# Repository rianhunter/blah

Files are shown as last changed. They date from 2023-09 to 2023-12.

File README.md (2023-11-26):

# [CXADC][cxadc] clock generator and audio ADC

A project to synchronously clock two (or more) [CXADC][cxadc] PCIe cards and an extra audio ADC from an external clock generator, for [VHS-Decode][vhs-decode] setups.
This enables sync capturing of the two RF streams (RF Video and RF HiFi audio from a VHS), in addition to a stereo audio stream (linear VHS audio).

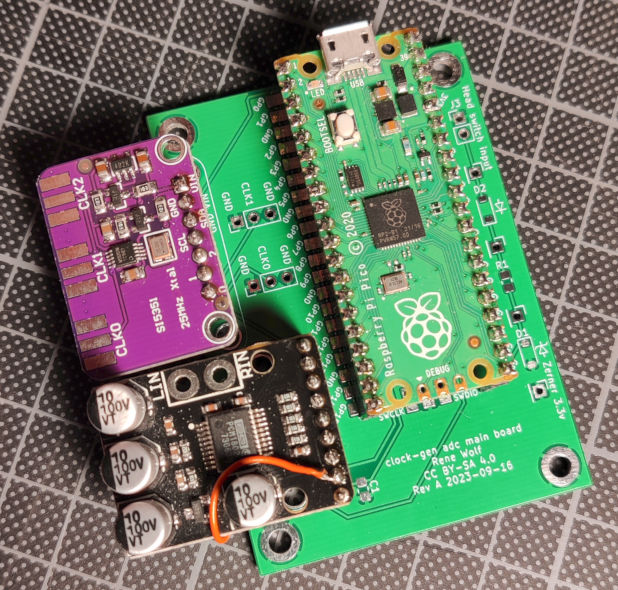
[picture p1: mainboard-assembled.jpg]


The above picture shows the mainboard, which you would typically mount inside your capture PC, along side the 2 CXADC cards.
The below diagram shows how a typical VHS capture is setup using the clock generator + audio ADC (this project).

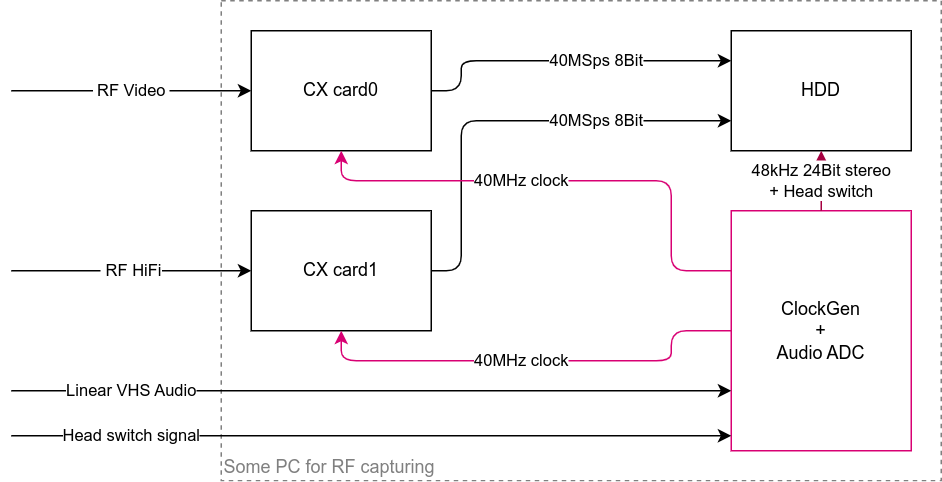
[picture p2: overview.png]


The project consists of 3 main components:
- A PCB adapter that is installed per PCIe card.
  It contains only a couple of passive components per [cx25800-11z data sheet][google-cx25800-datasheet].
- The main PCB that combines a [Raspberry Pi Pico][pi-pico], with an [Adafruit Si5351A Clock Generator Breakout Board][si5351-adafruit], and a [PCM1802 board][pcm1802-product].
- The firmware for the [Raspberry Pi Pico][pi-pico], that implements a USB sound card and also controls the [Si5351A][si5351-adafruit] clock generator.
  The firmware is available pre-build and can be flashed to the [Raspberry Pi Pico][pi-pico] without additional tools.

## Why you would need this

To capture VHS conveniently and then decode it with the amazing [VHS-Decode][vhs-decode], you need two [CXADC][cxadc] PCIe cards and an additional audio ADC.
One [CXADC][cxadc] card will capture the RF video stream at usually 20MSPS 10bit.
The other [CXADC][cxadc] card will capture RF HiFi audio at usually 10MSPS 8bit.
The additional audio ADC captures the linear audio track from the VHS.
So you have 3 independent pieces of hardware that each captures a part of the VHS tapes content.

Each of the 3 pieces has its own quartz oscillator, to drive its logic.
[CXADC][cxadc] PCIe cards usually come with a 28.6MHz quartz, that is commonly replaced with a 40MHz one for better performance.
The additional linear audio stream could be captured with an additional USB audio interface, which of course has its own quartz.

As every real device, quartzes have tolerances, resulting in frequency errors.
E.g. a 40MHz quartz might actually be 40.000005MHz or 39.999995MHz.
This error is due to manufacturing tolerance and basically random.
So each of the 3 quartzes will be slightly different, and you can't really know by how much.
If you just capture from one of these sources, then this tiny error does not matter.
But if you capture 3 streams that all come from the same source, a VHS tape, then it does!

So lets say that one [CXADC][cxadc] card is slightly faster than the other, because its quartz runs a bit faster than the others.
When you've finished your capture from both cards, one file will contain slightly more samples than came from the other stream.
This means the signal / information in both files is actually not aligned with each other any more, like it used to be on the VHS tape.
To align them again, you have to do (manual) post processing to find out how much they differ, and then *resample* one of them to fit the other.
The same goes for the linear audio as well, there may now be slightly more or less samples in your recorded wav file than expected.

This project solves all of this by replacing the quartz crystals on [CXADC][cxadc] PCIe cards with the output from a clock generator.
The clock generator produces the clocks for both cards from a single source (also a quartz).
This single source of course has a slight error, but as both [CXADC][cxadc] cards are now fed from the *same* source, both are now always in sync!
To also cover the linear audio capturing / recording, the project includes a [PCM1802 ADC][pcm1802-product].
This extra audio ADC is also synchronously clocked from the same clock generator, so it is also always in sync to the two [CXADC][cxadc] cards.

As an added bonus, the clock generator is programmable, so the output sample rates for the [CXADC][cxadc] cards can be changed!
This can be configured during system runtime, via the same USB audio interface that also streams the [PCM1802 ADC][pcm1802-product] samples.
And as one more feature, it also contains an additional digital input, that can be connected to the head switch signal of your VHS player.
This signal will be recorded along side the linear audio, enabling even more automation to sync up all those streams.

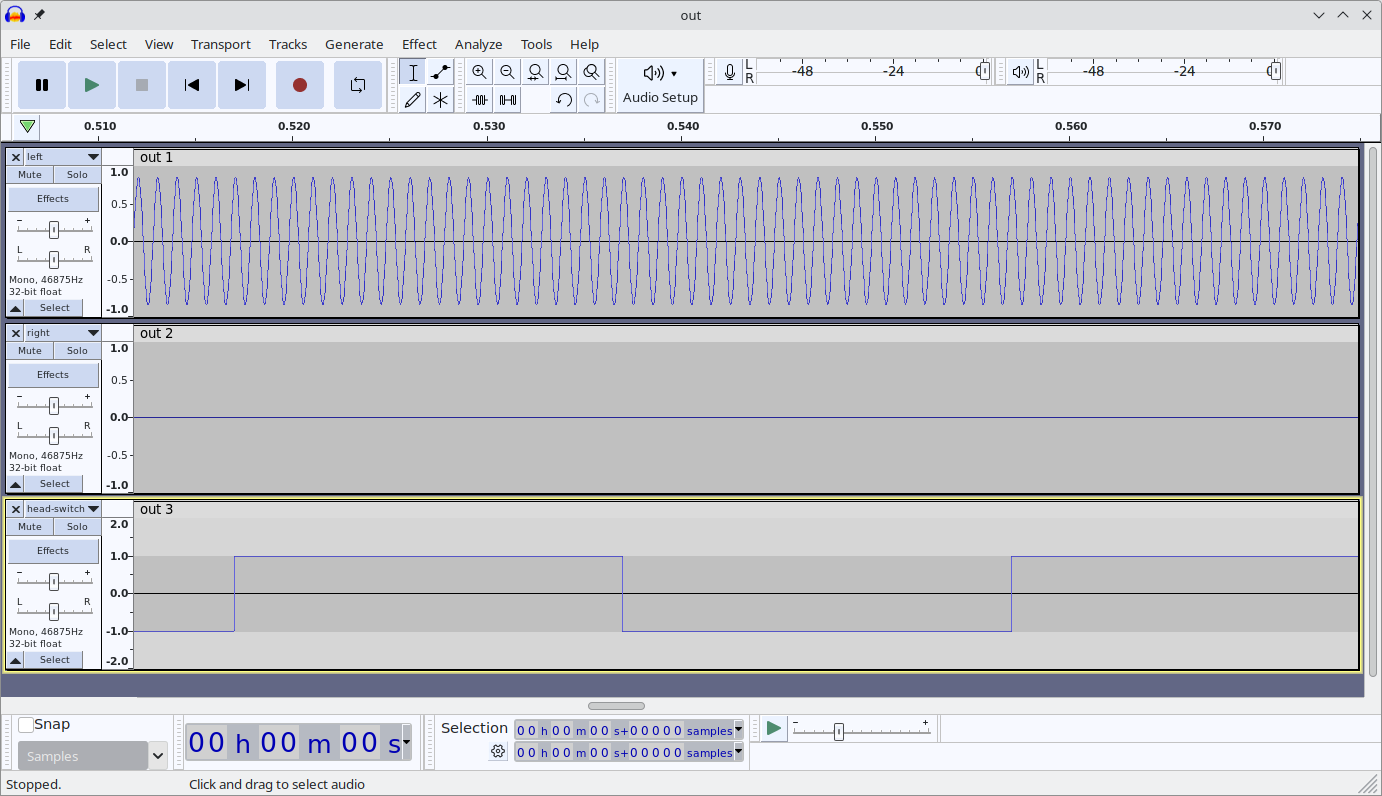
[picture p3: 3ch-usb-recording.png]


The above shows a 3ch recording as captured from the clock generator, a sine wave on the left, silence on the right, and a head-switch signal on the 3rd channel.
Read on to get all the details and find out how to build one yourself.

## Building one yourself

The build and installation guide can be found [over here][build-guide].
Have a look in the [mechanical section too](mechanical) for some (optional) 3D printable parts.
And once you built it, check out the [scripts][scripts] folder which holds some useful tools an examples around using this project.

## System overview and architecture

So you want to contribute, or just understand how it all works, then read on!
Lets start with a logical block diagram of the system.

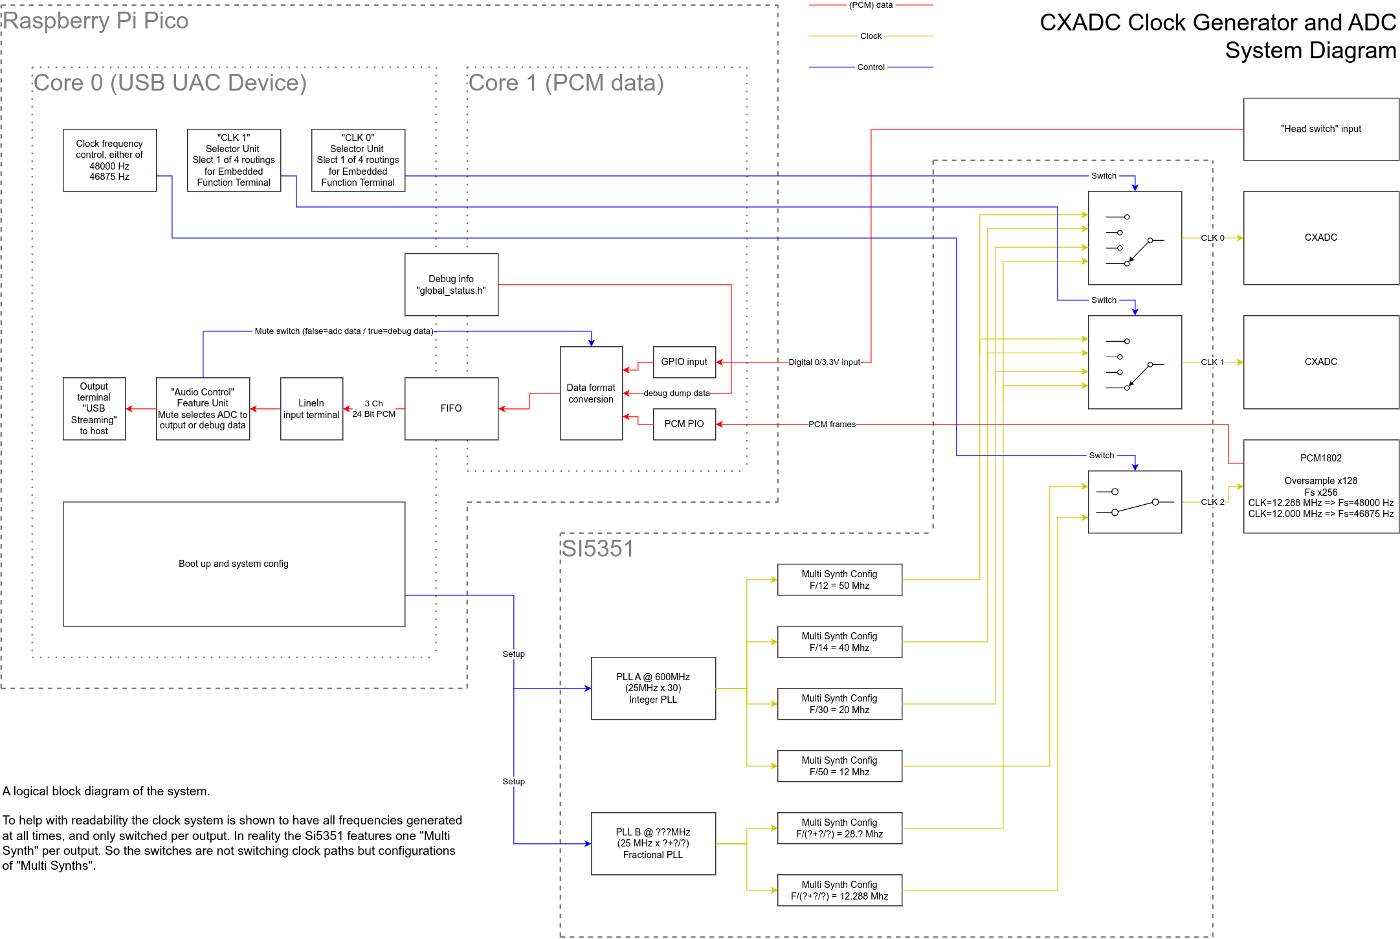
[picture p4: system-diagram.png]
system diagram


The brain of the system is a [Raspberry Pi Pico][pi-pico] that implements a [USB UAC][wiki-usb-uac] device (aka a usb sound card).
The [USB UAC][wiki-usb-uac] device can be used to stream the captured samples from the [PCM1802][pcm1802-product] as a regular sound source.
In addition to audio streaming it also offers control over the sample rates for the ADC and [CXADC][cxadc] cards.
[USB UAC][wiki-usb-uac] is supported by all major OS and should work without the need for any additional drivers.
Here's the output from `arecord` when the clock gen is plugged in:

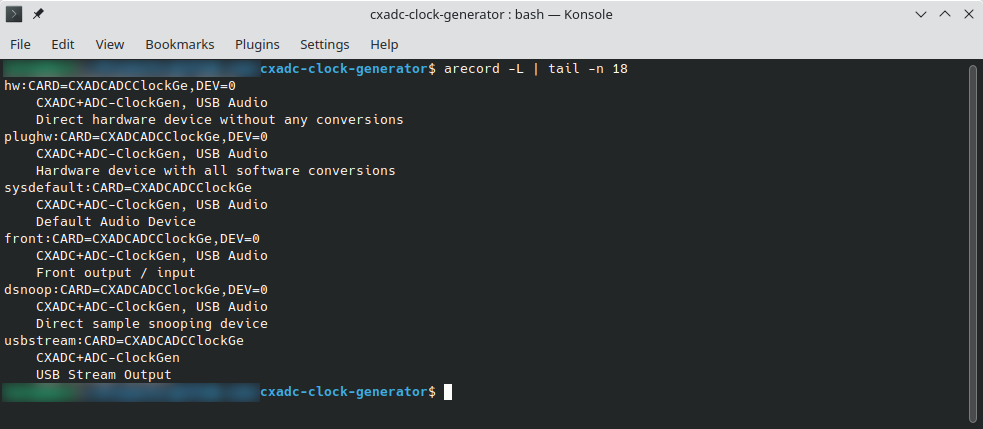
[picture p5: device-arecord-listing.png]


NOTE the following talks a lot about the implementation as a [USB UAC 2.0 audio device][wiki-usb-uac].
The backgrounds and details can be found in the "Device Class Specification Adopters Agreement", aka. [the USB audio specification][usb-auc-20-spec].
So you may want to read through the first 3 chapters to get the full background.

The [USB UAC device][wiki-usb-uac] offers two sample rates for the [PCM1802][pcm1802-product], that can be switched via a UAC clock source.
This is [done automatically by your OS / sound system][multi-samplerate] so just select your desired capture rate with your sound recorder of choice.
To enable clock frequency switching on the [CXADC][cxadc] cards however a UAC clock source would most likely not work.
ALSA and other sound systems will configure UAC clock sources only when capturing from a linked stream.
The [CXADC][cxadc] cards however are not linked to any audio data you could stream from the UAC device.
So instead the various clock rates are implemented as (fake) internal audio streams that can be switched with a UAC switch control.
Internal audio streams are per UAC specification not available to the outside and as such should not trouble OS sound systems for not offering a way to stream their data.
Every clock frequency is represented as one (virtual/internal/fake) input stream, and each of the two [Si5351A][si5351-adafruit] clock output is represented as one (virtual/internal/fake) output.
So to the OS / sound system this looks like a switch matrix of various audio stream sources, switched onto two outputs.
This will generate entries in the usual mixer widgets / apps, that let you control your general sound card settings.
But instead of switching actual audio streams, the UAC selector unit of course switches clock frequencies for the attached [CXADC][cxadc] cards.

This is all a bit abstract, so here's how those switches are displayed in `alsamixer` (you can switch the rates simply using the arrow keys on your keyboard):

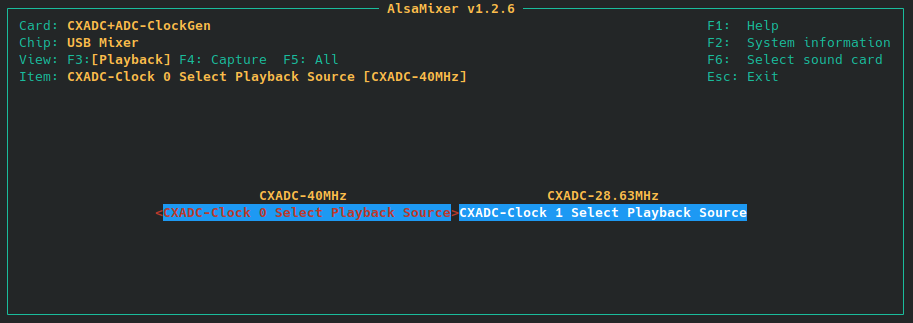
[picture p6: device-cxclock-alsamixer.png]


And here's how `amixer` can be used to script switching the clock rate on output 0:



To help with readability and to more closely match the USB UAC implementation, the above system diagram shows the clock system to have all frequencies generated at all times, and then switched per output.
In reality the [Si5351A][si5351-adafruit] features only one "Multi Synth" per clock output. 
So the switches are not switching clock paths but rather configurations of "Multi Synths".

The setup offers a couple of options for both the [PCM1802][pcm1802-product] audio ADC and the [CXADC][cxadc], but not all of them are of equal quality.
Inside the [Si5351A][si5351-adafruit] clock generator, two [PLLs][pll-wiki] are used to generate intermediate frequencies.
Those intermediate clock are then further divided to get the desired clock frequencies at the 3 outputs.

PLL A is running in integer mode, which means only whole number multipliers are used, resulting in no added [jitter][jitter-wiki].
Further more the subsequent "multi synth" dividers are also in integer mode, again resulting in no added [jitter][jitter-wiki].
But this limits the clock outputs options to only frequencies that can be produced by one multiplication and one division with only whole numbers.
Based on the 25 MHz source that is included on the [Si5351A][si5351-adafruit] board, this enables CXADC *sampling clocks of 20 MHz, 40 MHz and 50 MHz*.
The [PCM1802][pcm1802-product] needs a clock of 256 times the frequency of the desired output audio sampling rate.
The PLL A path generates a 12 MHz output which results in an exact (without rounding error) *46875 Hz / 46.875 kHz* sample rate for the audio stream.
This uncommon rate does not degrade the performance of the [PCM1802][pcm1802-product] ADC and offers analog bandwidth that is above CD quality.
Using common tools (sox or ffmpeg) the captured pcm data can be fully automatically resampled to the more common 48 kHz or 44.1 kHz in an offline processing step.

PLL B is running is running in fractional mode, yielding an increased clock [jitter][jitter-wiki].
Together with fractional configuration in the subsequent "multi synth" dividers, two more clock rates are possible.
The [CXADC][cxadc] can be clocked with the same frequency as the stock crystal 28.636360 MHz.
And the [PCM1802][pcm1802-product] can be clocked with a 12.288 MHz, giving the more common 48 kHz as output sample rate.
In ADCs [the higher the clock jitter the worse the sampling quality][jitter-paper] will be.
So you should avoid these sampling rates if you can and only use the ones from the integer mode PLL A.

## Debugging, global status and the mysterious mute switch

As this project is put together from various components (main board, sub boards, etc.), quite a few things can go wrong.
The firmware will output debugging information over the UART0 on the Pi Pico (GPIO0 / Pin1).
So hooking up a serial adapter is a good idea when working on the code (see also [dbg.h](firmware/src/dbg.h)).
However when just assembling the project, users may not have the option to do that, so a more practical way of obtaining debugging info is needed.
This does not have to be all the debug output that happens everywhere, but it should be enough to find common problems.

[USB UAC][wiki-usb-uac] unfortunately does not give many options to achieve that.
There is a "Memory Requests" (chapter [5.2.7.1][usb-auc-20-spec]) which would be perfect, but there is no common user space tool available.
User space support with regular tools is important as this is what users will have, and what the [collect-info.sh][scripts] script can use.
So instead of writing a custom tool, we just re-use the audio data that streams from the ADC.
But that can't be happening all the time, and the ADCs might even be non-working, so there must be a way to switch this on and off.
This can be done with a simple mute switch on a feature unit.
If muted debug info will be output, if un-muted (the default after boot), then actual ADC data will be streamed.

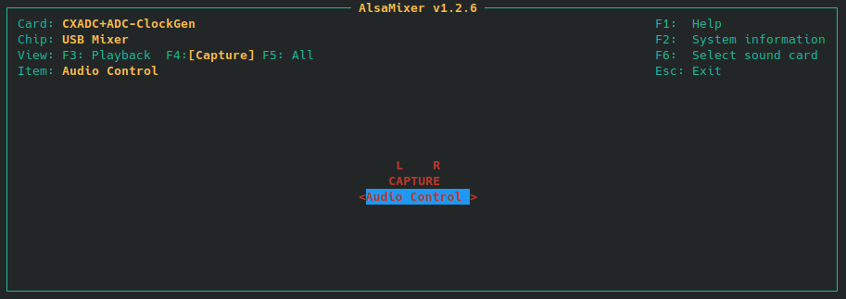
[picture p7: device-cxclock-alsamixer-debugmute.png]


The above shows how `alsamixer` displays the on / un-muted state (can be toggled with the *space* bar).

Now what is inside the debug info, you may ask?
Well there is a global status object [global_status.h](firmware/src/global_status.h) that is updated at the relevant places in the code.
It contains flags that indicate errors, and some other values of interest.
This object is dumped in the audio data and streamed to the host.
In other words, to get the debug data, just mute the stream and record a short piece of "audio" with `arecord`.

Have a look at the troubleshooting section of the [build guide][build-guide] if you need help getting the system running.

## Versioning

The firmware / software part is using [Semantic Versioning][semver], referring to the USB device interface.
Tags on this repository will carry the firmware / software version.

The PCBs are versioned with a letter revision.
These revisions do not imply any compatibility, and are solely used to differentiate one revision from another.
PCB revision overview:
- VT610ex clock generator adapter
  - Revision A - never released
  - Revision B - first public release
  - Revision C - some updates to the silkscreen and moved one via to get PcbWay support, otherwise identical to Revision C
  - Revision D - update connector footprint to better fit SMA edge connector and still be compatibile with pin header edge mount
- Clock generator main board
  - Revision A - first public release
  - Revision B - fixes the IO VDD for Si5351, which should be 3.3V, Rev A erroneously had it at VSys
  - Revision C - fixes the 3.3V from PCM1802 being driven by Pi Pico, instead this is an output and should be left open

## Changelog

See [CHANGELOG.md](CHANGELOG.md).

## Releases

See [releases](https://gitlab.com/wolfre/cxadc-clock-generator-audio-adc/-/releases) for PCB gerbers and firmware images ready to flash.

# License

The content of this repository is under various licenses.
The PCB parts are generally under *Creative Commons Attribution-ShareAlike 4.0*, but contains external sources (with compatible licenses).
The source code is mostly under 3-Clause BSD, but contains external sources with compatible licenses mixed in.
Source files carry an [SPDX][spdx] header to indentify.
For details see the individual *LICENSE\** files in the respective folders they apply to, firmware zip packages contain a copy of all the applicable license files.

[cxadc]: https://github.com/happycube/cxadc-linux3/
[pi-pico]: https://www.raspberrypi.com/products/raspberry-pi-pico/
[si5351-adafruit]: https://www.adafruit.com/product/2045
[pcm1802-product]: https://www.ti.com/product/PCM1802
[google-cx25800-datasheet]: https://www.google.com/search?q=DSH-201233A
[semver]: https://semver.org/
[wiki-usb-uac]: https://en.wikipedia.org/wiki/USB#Audio_streaming
[multi-samplerate]: https://stackoverflow.com/questions/41702932/usb-audio-class-2-0-how-to-support-multiple-bit-rates-sample-rates
[pll-wiki]: https://en.wikipedia.org/wiki/Phase-locked_loop
[jitter-wiki]: https://en.wikipedia.org/wiki/Jitter
[jitter-paper]: https://www.analog.com/media/en/reference-design-documentation/design-notes/dn1013f.pdf
[spdx]: https://spdx.dev/
[vhs-decode]: https://github.com/oyvindln/vhs-decode
[usb-auc-20-spec]: https://www.usb.org/sites/default/files/Audio2.0_final.zip
[scripts]: scripts
[build-guide]: build-guide/README.md

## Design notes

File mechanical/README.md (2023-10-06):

# Mechanical parts of the project

This folder holds mechanical parts, like enclosures or pc case brackets.

## [enclosure-01](enclosure-01)

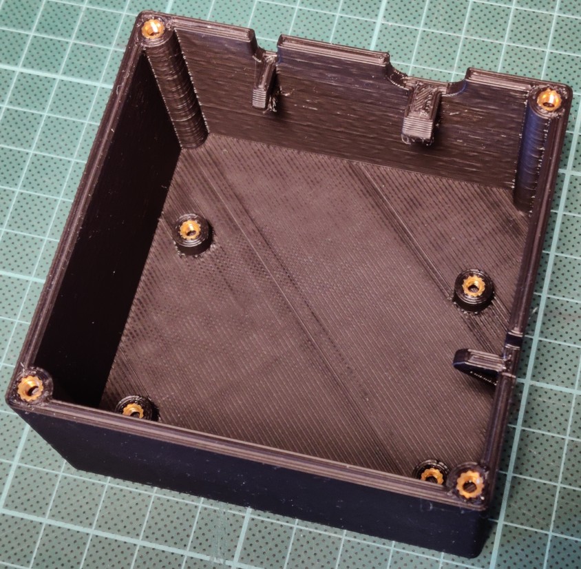
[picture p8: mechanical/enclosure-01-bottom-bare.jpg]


This is a simple box enclosure with enough room for all PCBs.
Can be printed in simple PLA on regular 3D printers.
Designed for M3 threaded insert from [CNC Kitchen](https://cnckitchen.store/products/gewindeeinsatz-threaded-insert-m3-short-100-stk-pcs), but possibly fits others a well.
FreeCAD model is fully parametric so you can change as needed (have a look at the included sheet called "m" to change heat set inserts diameters).

Optionally lined with copper for shielding.

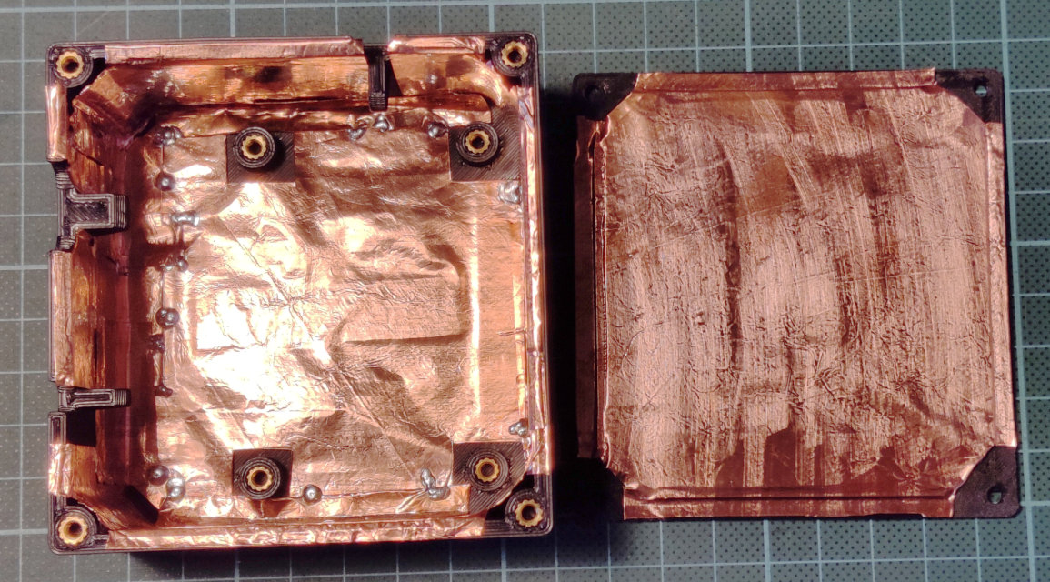
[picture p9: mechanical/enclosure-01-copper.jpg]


Optionally with a mounting base and retaining clip.
The mounting base can be glued into a PC case, and the enclosure box can be seated into it, then fixated with the retaining clip.

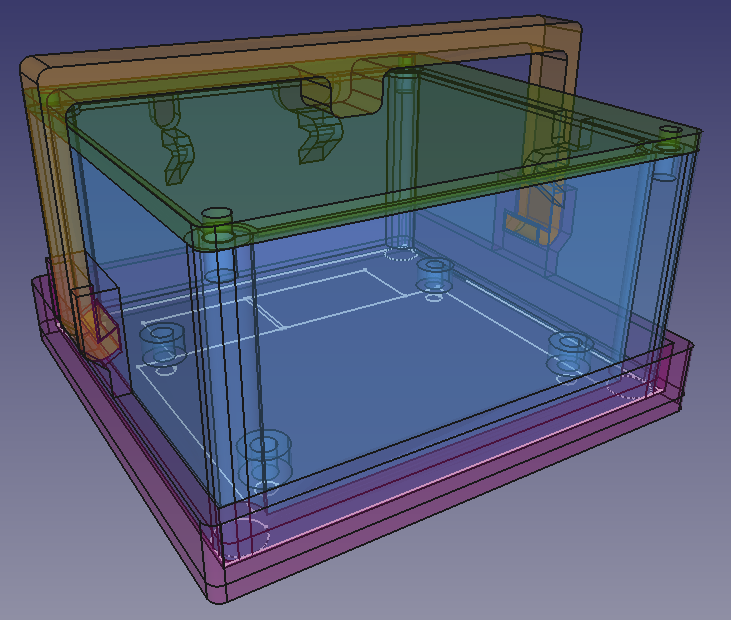
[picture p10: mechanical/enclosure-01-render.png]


## [pc-bracket-rca](pc-bracket-rca)

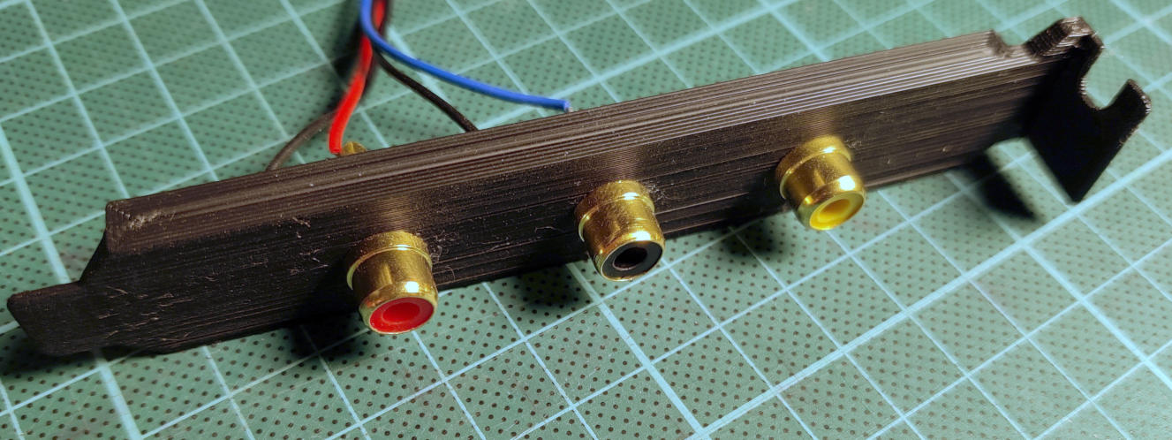
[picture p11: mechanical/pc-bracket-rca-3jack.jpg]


This is a simple PC card bracket with either 2 or 3 RCA jacks.
Can be used for PCM1802 ADC input (L+R) and optionally head switch input on the 3rd jack.
Printable in simple PLA on regular 3D printers.
FreeCAD model is fully parametric so you can change as needed (have a look at the included sheet called "m-rca" to change RCA jack hole diameters).

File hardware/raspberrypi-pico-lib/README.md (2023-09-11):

# KiCad-RP-Pico

A 3D footprint of the Raspberry Pi Pico board for KiCad.
To remove the need for git submodules and thus possibly broken KiCad projects, the symbol lib was copied to this repository.
The original project source can be found [over here][src].
A tweet with an image of your Raspberry Pi Pico project with a link [to the original project][src] and author (@tpcware) would be greatly appreciated.

[src]: https://github.com/ncarandini/KiCad-RP-Pico/tree/main

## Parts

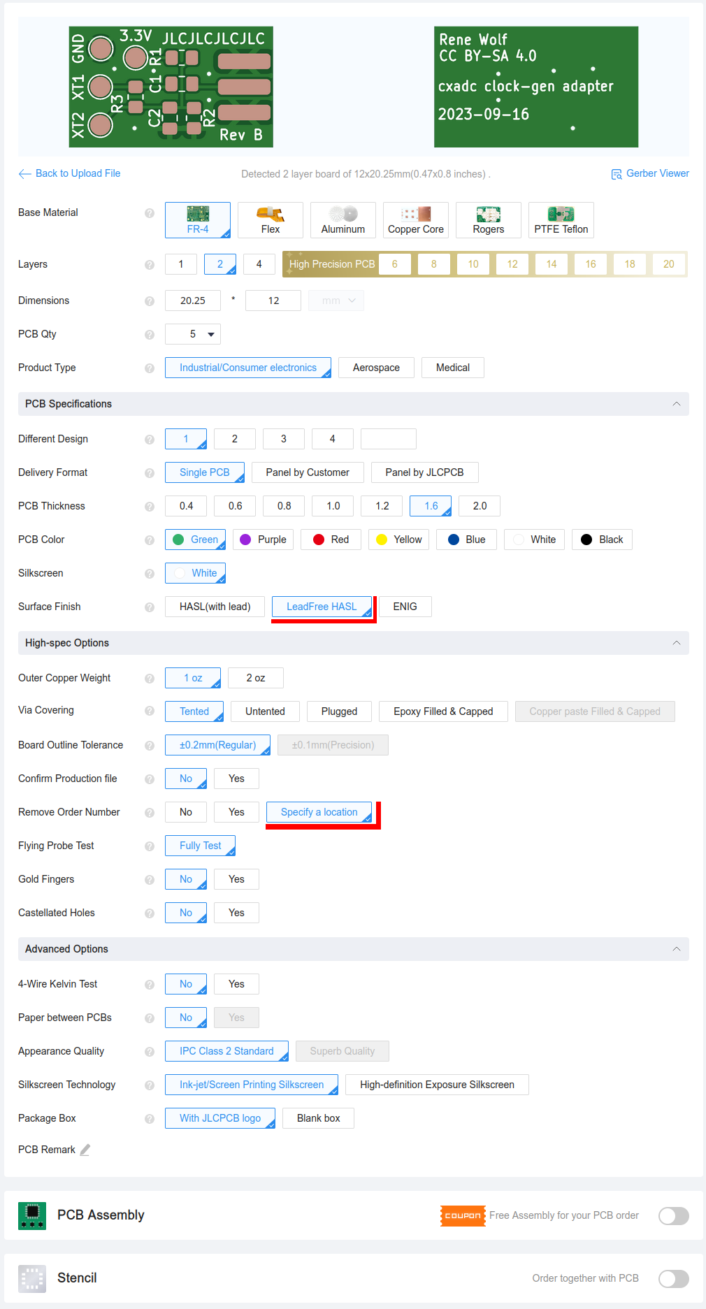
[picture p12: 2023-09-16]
hardware/jlc-2023-09-order-example.png

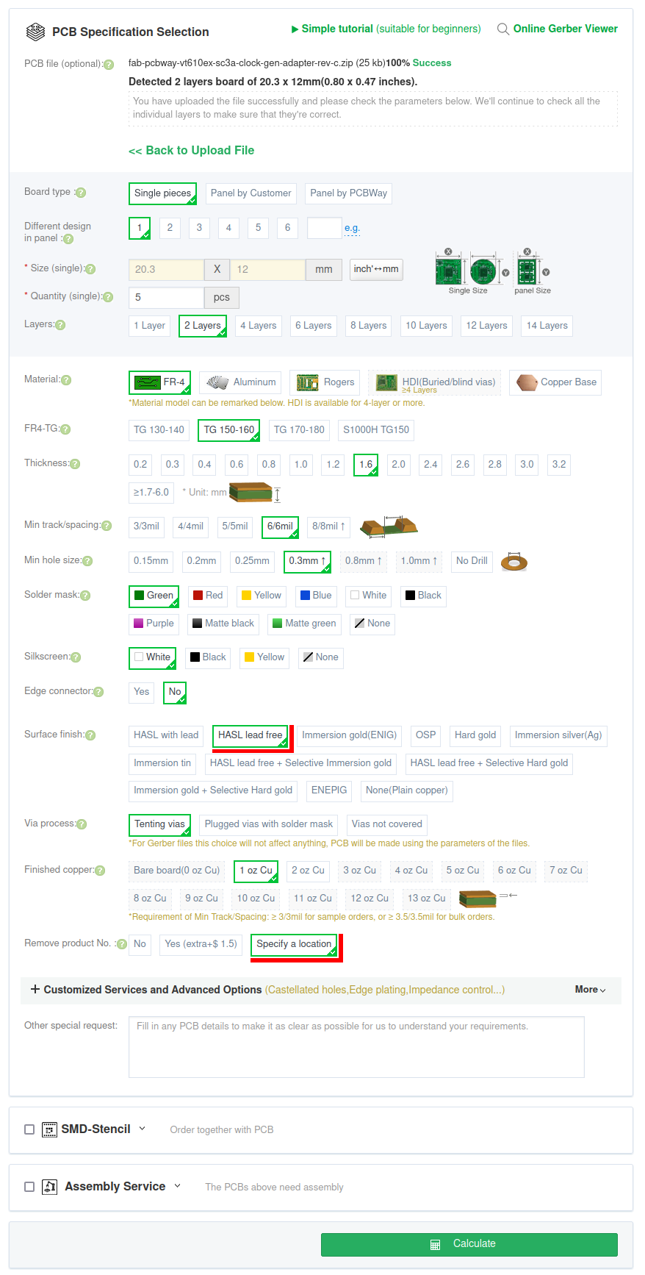
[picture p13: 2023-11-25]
hardware/pcbway-2023-11-order-example.png

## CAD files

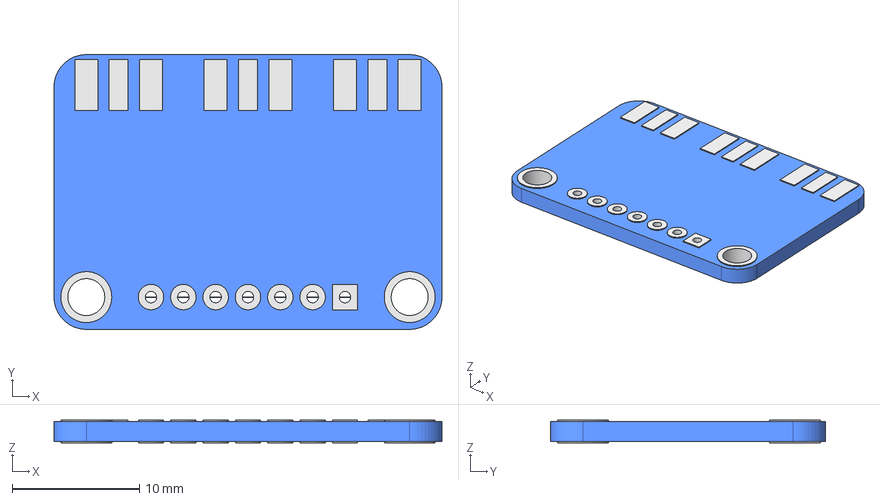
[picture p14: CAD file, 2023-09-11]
hardware/main-board/adafruit-si5351-freecad/adafruit-si5351-breakout.FCStd
30.5 x 21.6 x 1.80 mm
pcb
pads-th
pads-smd

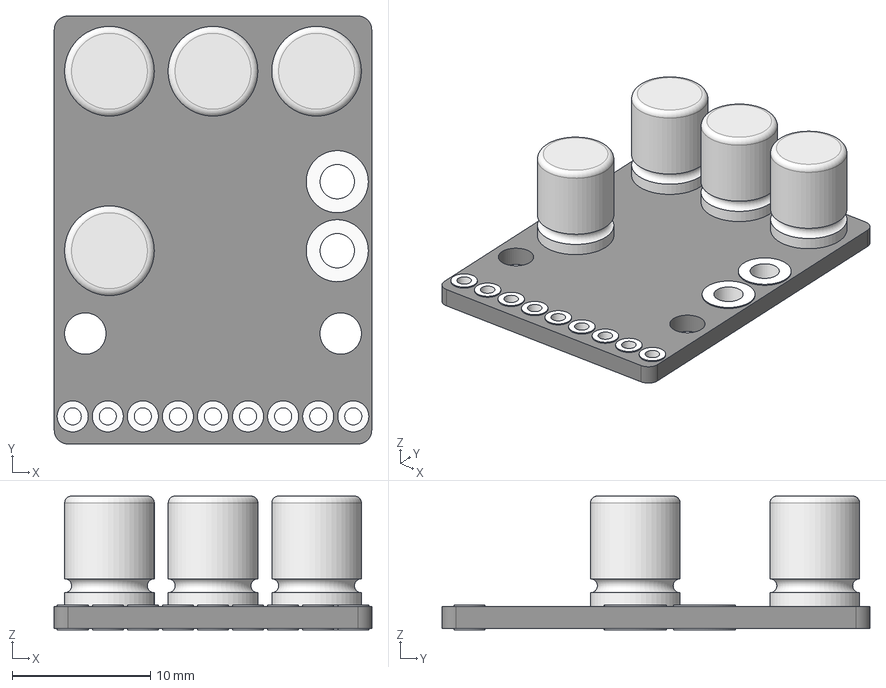
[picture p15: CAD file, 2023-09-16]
hardware/main-board/black-pcm1802-freecad/black-pcm1802-breakout.FCStd
23.0 x 31.0 x 9.70 mm
pcb
hole-plating
cap-back-1
cap-back-2
cap-back-3
cap-middle-1

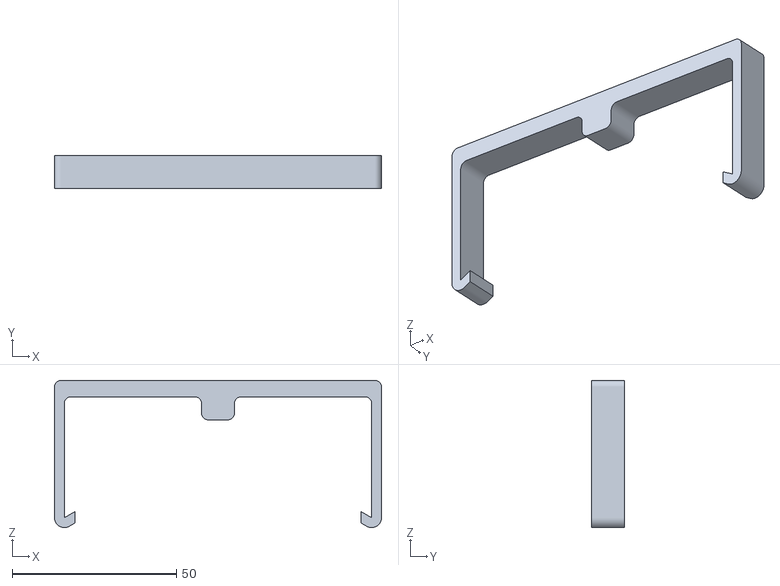
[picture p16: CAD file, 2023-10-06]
mechanical/enclosure-01/mount-clip.stl
99.5 x 10.0 x 44.8

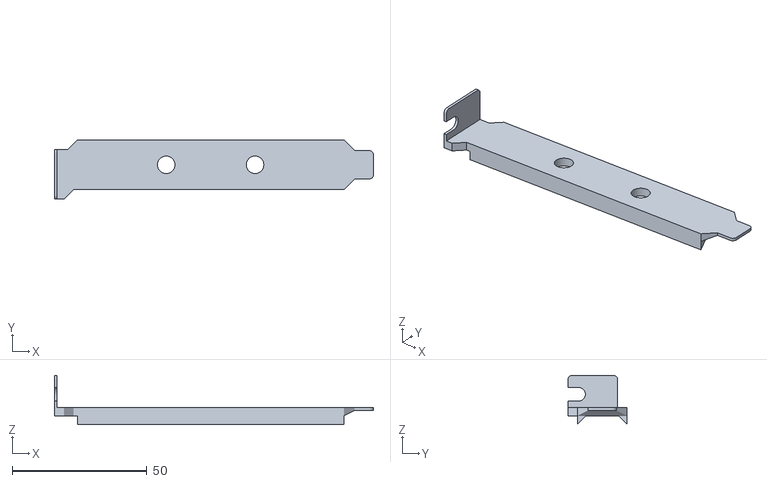
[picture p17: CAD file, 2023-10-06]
mechanical/pc-bracket-rca/bracket-2rca.stl
118.5 x 22.0 x 18.2

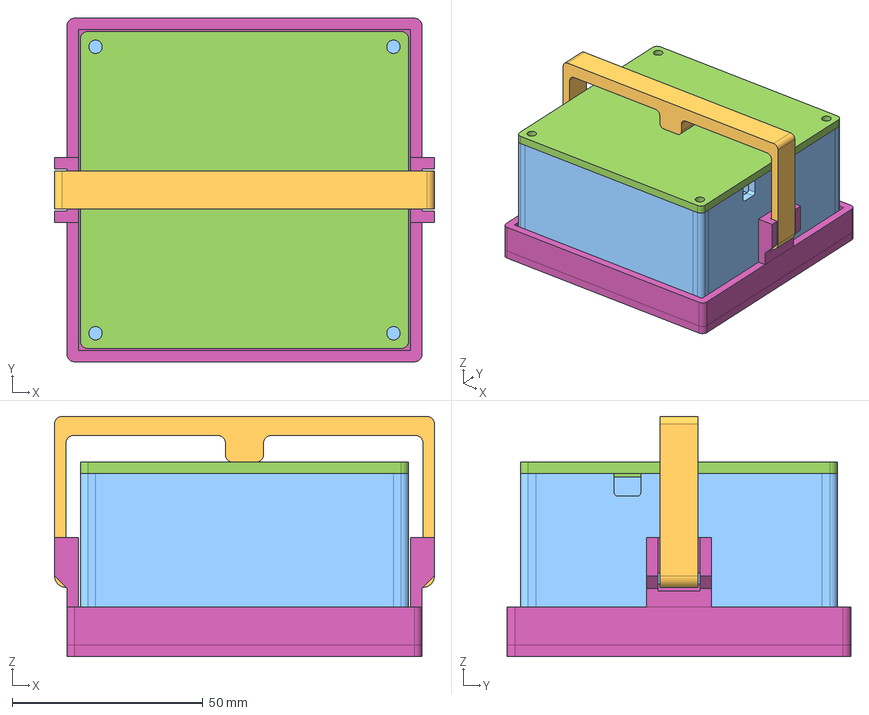
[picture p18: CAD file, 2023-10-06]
mechanical/enclosure-01/enclosure-01.FCStd
99.5 x 90.0 x 62.9 mm
box-bottom
box-lid
mount-clip
mount-base

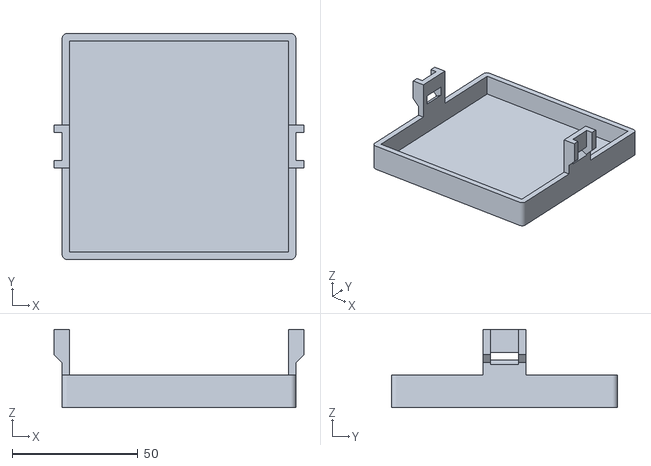
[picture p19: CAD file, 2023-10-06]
mechanical/enclosure-01/mount-base.stl
99.5 x 90.0 x 31.1

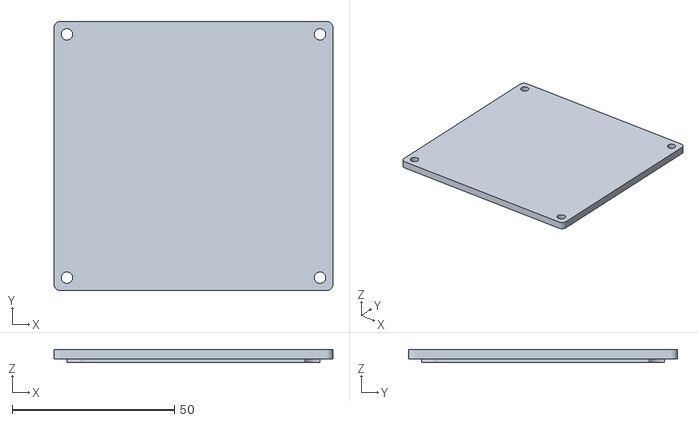
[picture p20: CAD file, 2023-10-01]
mechanical/enclosure-01/box-lid.stl
86.0 x 83.0 x 4.00

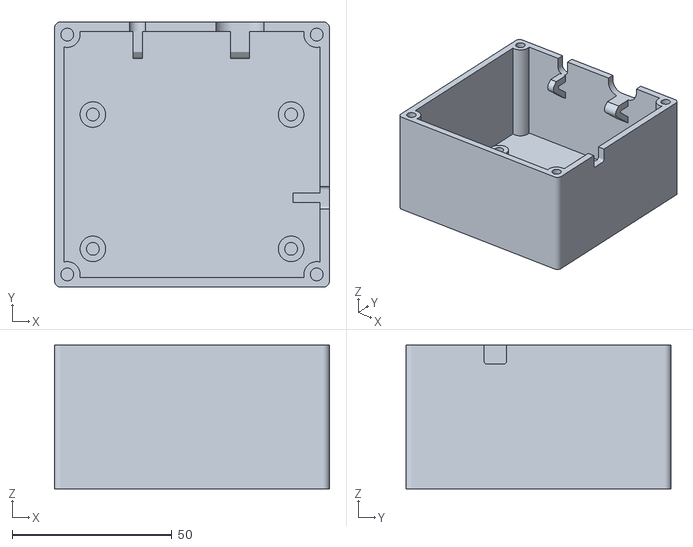
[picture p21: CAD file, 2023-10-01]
mechanical/enclosure-01/box-bottom.stl
86.0 x 83.0 x 45.0

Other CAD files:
mechanical/pc-bracket-rca/bracket-3rca.stl
mechanical/pc-bracket-rca/pc-bracket-rca.FCStd

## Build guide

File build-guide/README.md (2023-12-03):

# Build and installation guide

Ahh so you've come here to build the project, *excellent*!

Before you start ordering and building, you should read the entire guide at least once so you know what to expect.
You will be assembling the project from various ready made components and solder them together.
Most components can be ordered in a finished and populated state, basically you only need to wire them up.
But the two main PCBs of this project need to be ordered with either [JLCPCB][jlcpcb] or [PcbWay][pcbway] and then some SMD parts populated manually.
Don't worry though all SMD parts are rather large 0805, and ordering them with [JLCPCB][jlcpcb] is fast and cheap!
The [hardware](../hardware) section of this project includes the full [KiCad][kicad] project files, so you can also generate gerbers for a different manufacturing house.

If you are new to soldering electronics, learning about it is a bit beyond this guide.
However you may want to start looking here, as these videos cover the things needed for this guide:
- Branchus Creations Beginner's Guide to Soldering Electronics [Part 1](https://www.youtube.com/watch?v=M2Jf8cebwCs) and [Part 2](https://www.youtube.com/watch?v=BPuH1Z2npoQ)
- Electronoobs [SMD Soldering Tutorial | Guide | Tools | Tecniques | Stencil](https://www.youtube.com/watch?v=fYInlAmPnGo)

The steps covered here will assemble the electronic components and flash the firmware on the Raspberry Pi Pico.
Mounting the finished build in your particular PC / setup is beyond the scope of this guide.
You can however have a look in the [mechanical section](../mechanical) for some 3D printable parts that may suit your needs.

This guide will assume you have two PCIe CX based capture cards ready to be modded.
Have a look [over here][vhs-decode-wiki-cxcard] for some sources and options on acquiring those cards.
The instruction in here possibly work with other models, but they were tested and confirmed working with these variants:
- *VT610EX Rev:SC3A VTImage 19.07* capture cards, white pcb, featuring a *CX25800-11Z*

If your board / card variant is not listed here, go over the guide and compare the instructions to your card.
If the parts they are referring to also exist on your board, there's a good chance this guide also works for you.

## General prerequisites

You will be dealing with high frequency digital clock signals.
Even though these are more immune to problems than analog signals, you should have a [Digital storage oscilloscope][wiki-dso] at hand.
You can assemble all of this project without one, but you probably want to check signal integrity, before putting everything together.
In order to correctly assess the signals, your scope should have an analog bandwidth of at least 20MHz, better 100MHz.

You should also have a [Multimeter](https://en.wikipedia.org/wiki/Multimeter#Digital) ready, to test continuity, and verify resistance and possibly capacity.

And finally you will need some basic soldering equipment. 
A fine tip (e.g. 1mm) soldering iron and some good lead-free solder.

Each of the PCBs has a shopping list of components you need to order.
For the SMD parts I always order some spares, in case I make a mistake.
So put add something like 10% additional parts, but at least one extra component per type.

## Ordering PCBs

If you choose a manufacturing house other than [JLCPCB][jlcpcb] or [PcbWay][pcbway], you already know what you need.
The [releases section][releases] of this project holds the finished gerbers for ordering directly from [JLCPCB][jlcpcb] or [PcbWay][pcbway].
When ordering from [JLCPCB][jlcpcb], you should check [these settings (valid as of Sep. 2023)](../hardware/jlc-2023-09-order-example.png) for both boards.
When ordering from [PcbWay][pcbway], you should check [these settings (valid as of Nov. 2023)](../hardware/pcbway-2023-11-order-example.png) for both boards.
The minimum quantity (as of Nov. 2023) is 5 per PCBs (on both manufacturing houses), so for a single clock gen with two [CXADC][cxadc] cards, you will have some spares.

## Building PCB 1 - VT610ex clock generator insert

This PCB adapter will replace the quartz oscillator on a VT610ex PICe capture card.
So you will need to build one these PCBs / adapters per [CXADC][cxadc] card you have.

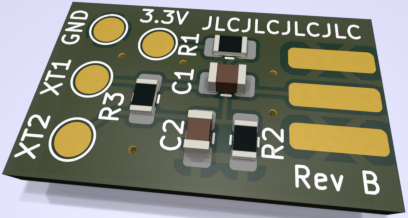
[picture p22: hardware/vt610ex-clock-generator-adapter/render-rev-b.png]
render


**Shopping list** for *one single* adapter (multiply items by number cards you want to modify):
- 1x PCB "clock-gen-adapter" probably from [JLCPCB][jlcpcb]
- 2x 0805 SMD resistor 1K Ohm, 5% tolerance or better
- 1x 0805 SMD resistor 10K Ohm, 5% tolerance or better
- 1x 0805 SMD capacitor 1.5 nF, 6V or greater, ceramic X5R or X7R
- 1x 0805 SMD capacitor 10 nF, 6V or greater, ceramic X5R or X7R
- Thin wire in 4 colors, AWG 30 (0.25mm) to AWG 20 (0.81mm) works well
- The PCB supports two options for connection to the mainboard
  - Either with pin header / socket and a custom made coax cable
    - 1x 3x2.54mm pin header, straight (it will be mounted "lying / sideways" on the PCB)
    - 1x 3x2.54mm pin socket, straight (it will be soldered as a connector to the coax cable)
    - About 50cm of RG174 coax cable.
      This will be used to connect the adapter to the clock gen mainboard, and the exact length depends on your installation situation.
      You can use a different type of cable here, but the RG174 is still flexible enough to be convenient to handle.
    - Some heat-shrink tube to cover the coax and pin socket
    - Double sided tape to attach the adapter PCB to the back of the CX card
  - Or via SMA edge connectors, which should be paired with another one on the Si5351A sub board
    - 2x Female edge mounting SMA connectors (one for the adapter, and one for the mainboard / Si5351A sub board).
      There are a number of manufacturers that produce these, but they should be about 6-7mm side-to-side, and have a 1.6-1.8 mm PCB clearance, e.g [CON-SMA-EDGE-S](https://mou.sr/3t0dMKq)
    - 1x Male to male SMA cable with a length matching your installation requirements, e.g. [250mm 135101-03-M0.25](https://mou.sr/3Tggbf5)
    - Thick double sided tape to attach the adapter PCB to the back of the CX card.
      Thickness must give enough clearance for the edge mounting SMA connectors, about 2mm should be fine.

First populate the SMD components on the PCB like so:
- R1, R2 as 1K Ohm
- R3 10K Ohm
- C1 1.5 nF
- C2 10 nF

Then solder the 3x pin header sideways onto the edge of the PCB, or solder the edge mounting SMA connector.
Finally solder about 10 cm (4 inches) of wire to each of the pads (XT1, XT2, GND, 3.3V).
Use different colors per pad for easier installation.
You should end up with something like this (pin header shown, not SMA edge connector):

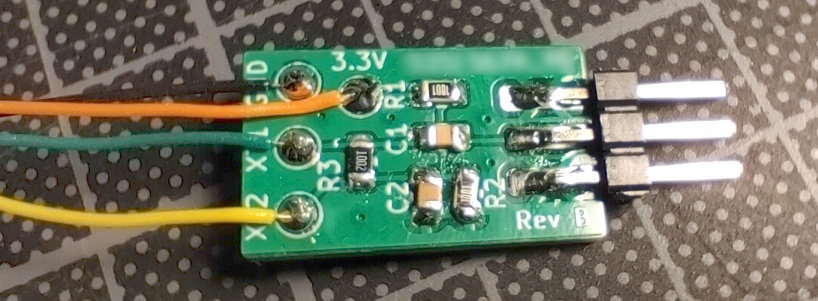
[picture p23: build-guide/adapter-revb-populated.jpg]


If you chose the SMA connector option, this completes the adapter board.

Otherwise you now need to finish the coax cable and connection.
So take the desired length of RG174 coax cable and solder the 3x pin socket to one end.
Remember you can always shorten the cable later, so add some extra length here.
The center pin is the clock signal, the other two pins are shield / ground.
Finally with some heat shrink over it, you should end up with something like this:

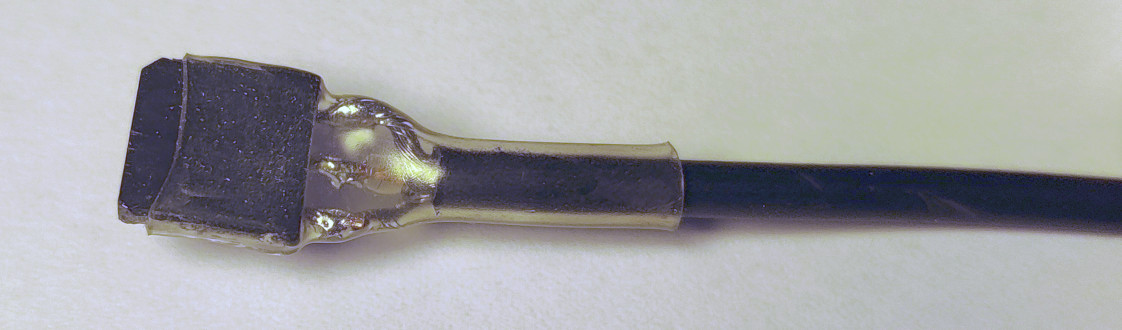
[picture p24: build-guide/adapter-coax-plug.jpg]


This completes the adapter board, so it can be later mounted to a CX card.

## Building PCB 2 - Clock generator and ADC mainboard

This PCB combines a [Raspberry Pi Pico][pi-pico] with a [Adafruit Si5351A Clock Generator Breakout Board][si5351-adafruit], and a [PCM1802 board][pcm1802-product].
The clock generator produces 3 clocks, clock 0 and clock 1 are available for two [CXADC][cxadc] cards, clock 2 drives the [PCM1802 ADC][pcm1802-product].
Optionally a digital input pin can sample the *head switch signal* from your VCR, or any other sync signal you choose.

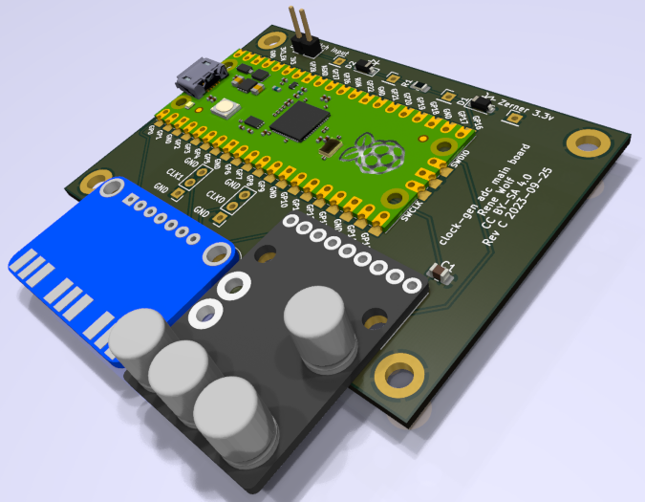
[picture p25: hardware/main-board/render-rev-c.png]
render


The various sub components can be soldered / mounted on the mainboard, with only pin headers as connection.
However adding pin sockets will enable easy component swapping later, and greatly help with troubleshooting!

**Shopping list mandatory components only** for one mainboard:
- 1x PCB "clock-gen mainboard" probably from [JLCPCB][jlcpcb]
- 1x [Raspberry Pi Pico][pi-pico] (wireless variant can be used, but is not needed, and offers no extra features)
- 1x [Adafruit Si5351A Clock Generator Breakout Board][si5351-adafruit], compatible clones may be found at other places as well.
  If you chose to use SMA edge connectors for the clock lines then the mechanical stress will be taken up by the Si5351A sub board instead of the mainboard PCB.
  Depending on your specific installation, you should add some mechanical support here.
- 1x PCM1802 board, unknown manufacturer but can be [found on aliexpress][ali-pcm1802-search].
- 1x Micro USB cable to connect the Raspberry Pi Pico to your target system.
- 2x 20x2.54mm pin header, straight (mounting the Raspberry Pi Pico)
- 1x 9x2.54mm pin header, straight (mounting the PCM1802 board)
- 1x 7x2.54mm pin header, straight (mounting the Si5351A board)
- About 50cm of shielded, stereo audio cable to connect the PCM1802 stereo inputs to some connector.
  I can recommend [SOMMER Cable SC-Cicada SO-D14](https://shop.sommercable.com/en/Cable/Bulk-Cable-Audio/Patch-Mikrofonkabel-SC-Cicada-SO-D14-200-0451.html) or the [Belden 8451](https://www.belden.com/products/cable/audio-cable/analog-audio-cable/8451).
  The exact length depends on your installation situation.
- 2x RCA socket for stereo analog input.
  Feel free to choose a different connection type for your setup.
  This build guide will skip over this part, and it is listed here only to remind you to include this in your shopping spree.

**Shopping list optional components** for one mainboard, in addition to the list above:
- 2x Heat sinks for the CX chips, with adhesive thermal pads to mount.
  As the clock generator will deliver higher clock frequencies than the stock crystal, the chips will get warmer.
- 2x 20x2.54mm pin socket, straight (making the Raspberry Pi Pico removable again)
- 1x 9x2.54mm pin socket, straight (making the PCM1802 board removable again)
- 1x 7x2.54mm pin socket, straight (making the Si5351A board removable again)
- 1x 0805 SMD capacitor 10 µF, 6V or greater, ceramic X5R or X7R.
  This can be used to further decuple the 5V analog rail on the PCM1802 chip.
  It is unlikely you will need this unless your USB 5V supply is quite bad.
  But then you probably should not be using the system to capture analog RF signals either ...

**Shopping list for optional head switch signal input** for one mainboard, in addition to the lists above (can be left entirely unpopulated if you don't need that):
- 1x 0805 SMD resistor 1K Ohm, 5% tolerance or better.
- 1x 3.3V Zener diode either SMD SOD-123 package or through hole
- 1x regular signal diode either SMD SOD-123 package or through hole
- 1x 2x2.54mm pin header, straight (serves as a connection point on the PCB for the signal input).
- 1x 2x2.54mm pin socket, straight (serves as a connector plug).
- About 50cm of shielded, cable for the head switch signal.
  This signal is rather low frequency and digital, so most cables should work.
  You can just use the same shielded (stereo) audio cable from the PCM1802 connection.
  The exact length depends on your installation situation.
- 1x RCA socket for head switch signal input.
  Feel free to choose a different connection type for your setup, e.g. BNC, SMA, what ever works for you.
  This build guide will skip over this part, and it is listed here only to remind you to include this in your shopping spree.

First we need to configure the PCM1802 board, and fix a design bug on it.
The under side of the board has a couple of solder bridges to configure the PCM1802, and we want to bridge both `MODE0` and `MODE1`.
However this board (at least the ones I bought in 2022), have a bug: the `+` side of the solder bridges is *not* connected to 3.3V.
You can confirm with your Multimeter, there is no continuity between the `+` connections and the 3.3V terminal.
This can be easily fixed with an additional bodge wire from the bottom to the top side.
Make sure to install the pin header first, then run the bodge like so:

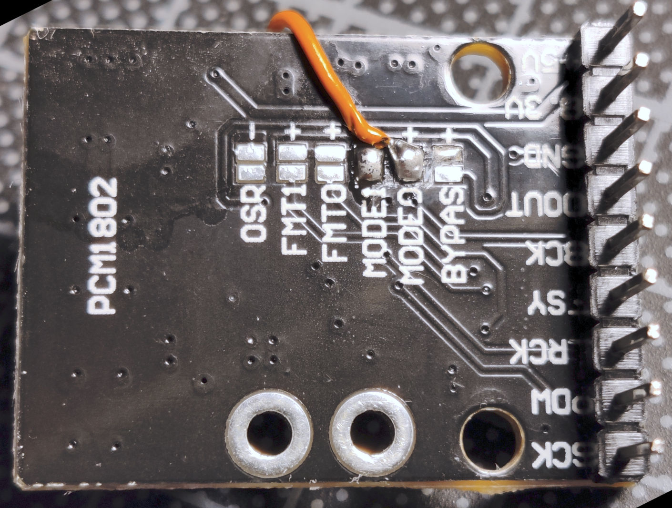
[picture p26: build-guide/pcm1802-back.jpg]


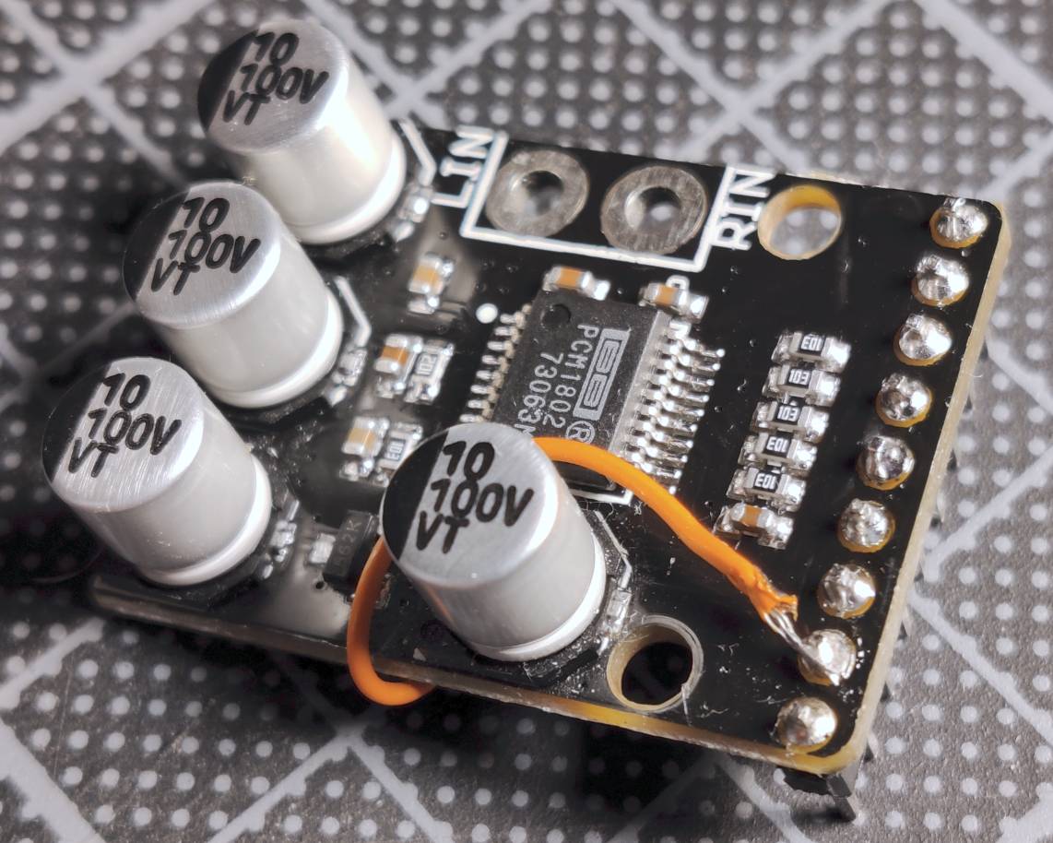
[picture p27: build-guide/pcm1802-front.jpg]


Next populated the remaining pin headers, and optionally sockets, on the mainboard, Raspberry Pi and Si5351A.
The Si5351A board may have come with SMA edge connectors, which can be used to connect the clock lines to the adapter boards (check that they are the opposite of your male cables).
So if you chose to use SMA edge connectors, then instead of later soldering the coax directly to the mainboard, you can populate and use those.

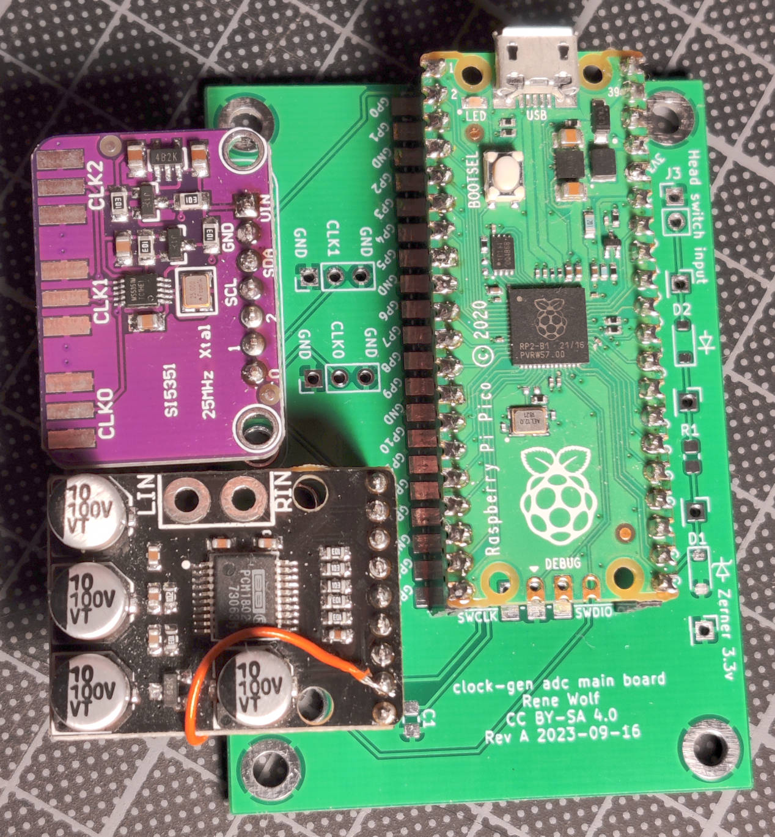
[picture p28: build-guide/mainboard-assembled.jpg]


Solder the stereo audio cable to the PCM1802 L and R inputs.
Finally solder your RG174 coax cables to the clock outputs 0 and 1 on the mainboard, or populate the SMA edge connectors on clock 0 and 1 of the Si5351A sub board.
This completes the mandatory part, and you can move on to the next section.

Optionally you can populate C1 with the 10 µF cap.

Optionally if you want the head switch input, you need to populate some additional things:
- R1 with 1K Ohm
- D1 with the 3.3V zener diode (observe polarity as per markings on the PCB)
- D2 with the regular switching diode (observe polarity as per markings on the PCB)
- J3 with the pin header for connection
- any additional work for cabling this up, as per your setup needs

## Installation

This section deals with the overall installation of the previously build components.
The firmware section is common to all card variants, but the adapter PCB install may differ.
So after installing the firmware, skip over to what ever section matches your CX card variant.

### Installation - firmware

By now you can flash the firmware to the Raspberry Pi and test whether its clock outputs are working.
Download the firmware zip file from the [releases][releases] page, and get your [Digital storage oscilloscope][wiki-dso] ready.

Do not connect the adapter boards yet, just leave the coax cable unconnected.
Locate the *.uf2* file in the zip and [flash it to the Raspberry Pi Pico](https://www.okdo.com/getting-started/get-started-with-raspberry-pi-pico/).
This will automatically restart the Pico and it will register as a UAC audio device.
The LED on the Pico should be be flashing regularly (about once every second).

Check `dmesg` to see this:

```dmesg
[121467.020996] usb 1-1: new full-speed USB device number 7 using xhci_hcd
[121467.171072] usb 1-1: New USB device found, idVendor=1209, idProduct=0001, bcdDevice= 1.00
[121467.171084] usb 1-1: New USB device strings: Mfr=1, Product=2, SerialNumber=3
[121467.171090] usb 1-1: Product: CXADC+ADC-ClockGen
[121467.171095] usb 1-1: Manufacturer: Rene Wolf
[121467.171099] usb 1-1: SerialNumber: XXXXXXXXXXXXXXXX
```

And `arecord -L` should include this:

```
hw:CARD=CXADCADCClockGe,DEV=0
    CXADC+ADC-ClockGen, USB Audio
    Direct hardware device without any conversions
```

Your Pico is now setup, and next we'll check the clock outputs.
Locate the pins labeled *0,1,2* on the Si5351A pin header, each corresponds to one clock signal output.
With your scope check that the following default frequencies are generated:
- Clock 0 - 28.6 MHz
- Clock 1 - 28.6 MHz
- Clock 2 - 12.288 MHz

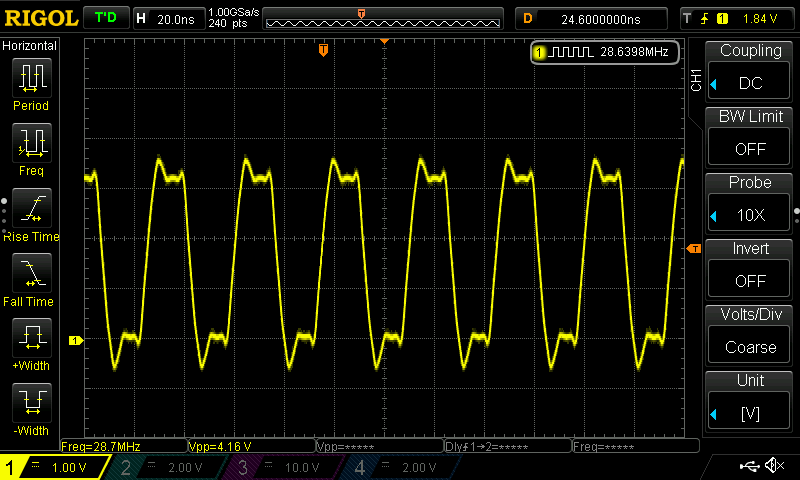
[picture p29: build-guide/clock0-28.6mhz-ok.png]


The image above show how the 28.6 MHz output on clock 0 should look.
If all the clock outputs look reasonable, this concludes the firmware installation.
You can move on to prepare the CX cards.

### Installation - adapter - *VT610EX Rev:SC3A VTImage 19.07* card

The following steps will remove the onboard quartz clock source and add the adapter board to hook up the clock gen.
Beware that a CX card without a clock source will prevent a PC from booting!
So after you removed the components you need to have an external clock source on your card if its plugged into your PC.

This card has 4 components that need to be removed: Y1 (crystal), C22, C19, R12.
The following image shows them marked in pink:

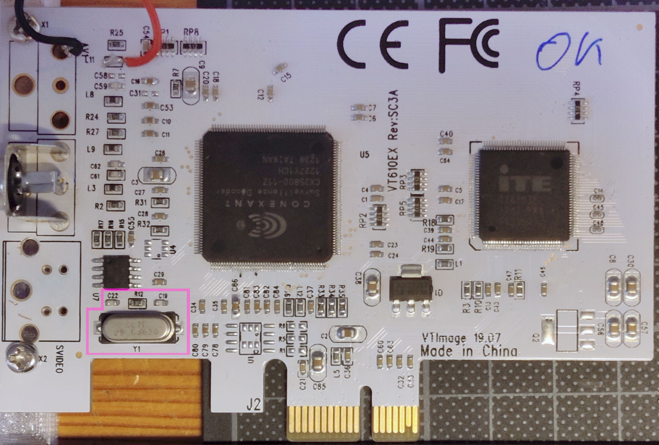
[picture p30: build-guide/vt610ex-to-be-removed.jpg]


With the components removed, turn the card around and using double sided tape attach the adapter PCB like so:

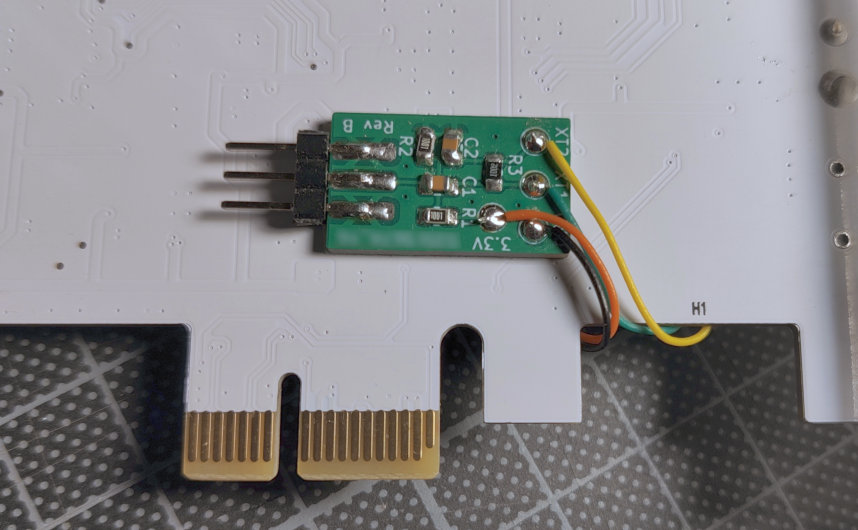
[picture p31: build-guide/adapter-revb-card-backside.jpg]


Turn the card to the front again, and solder the 4 wires from the adapter board.
3.3V and GND can be tapped from C85, XT1 and XT2 are the two pads of the crystal.
The following image shows the finished mod, the hand written *1* and *2* denote the *XT1* and *XT2* lines, and the previously removed and now unpopulated components marked in pink once more:

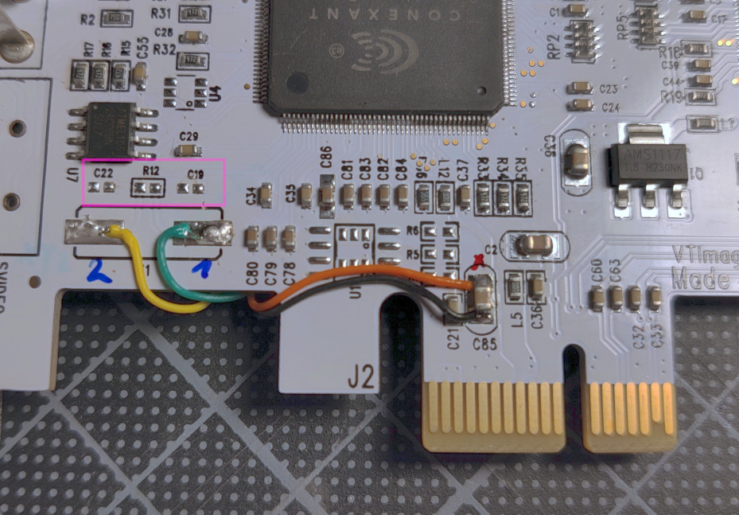
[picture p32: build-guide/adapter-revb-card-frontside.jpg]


This completes the adapter board installation.

### Installation - finished setup

When you are finished with your CX card(s), you are pretty much done.
Here's how this looks with one card attached to the clock gen mainboard:

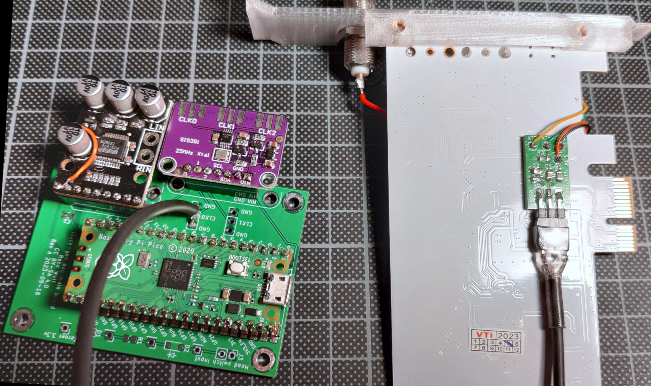
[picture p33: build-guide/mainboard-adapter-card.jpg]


NOTE this image misses the audio cable, and has the optional head switch input unpopulated.

You can now install the CX cards and the clock gen into your PC.
Also install any additional connection (e.g. audio and head switch RCA plugs) and wire them up as per your liking.
After booting your PC, all CX cards should show up as usual, and capturing should work as normal.
Using `alsamixer` (press F6 to choose your card) you can now switch clock rates on both cards.
To test PCM1802 audio ADC capture, you can run `arecord -D hw:CARD=CXADCADCClockGe -c 3 -r 48000 -f S24_3LE out.wav`.

That's it you are ready for some sync RF capture!

## Troubleshooting

As with any complex system, you may encounter problems.
The information in this section should help to find the cause for common problems when assembling the setup.
Be aware that troubleshooting and debugging is also an art and improves with experience.
So the guide and advise here can never catch all cases and you are encouraged to think about the steps you take.

Notes:
- Any commands shown are *case sensitive* so make sure to type them exactly as show here
- The screw terminals on the mainboard are GND
- The guide assumes you did check GND for continuity across all sub boards and to the USB connector
- Have the Raspberry Pi Pico [pinout](https://www.raspberrypi.com/documentation/microcontrollers/raspberry-pi-pico.html) at hand for referencing pin locations

With that out of the way, start by following the path in this diagram, details on relevant step are explained further down.
Don't be intimidated by the size, just follow the arrows, start on the left :grin:.

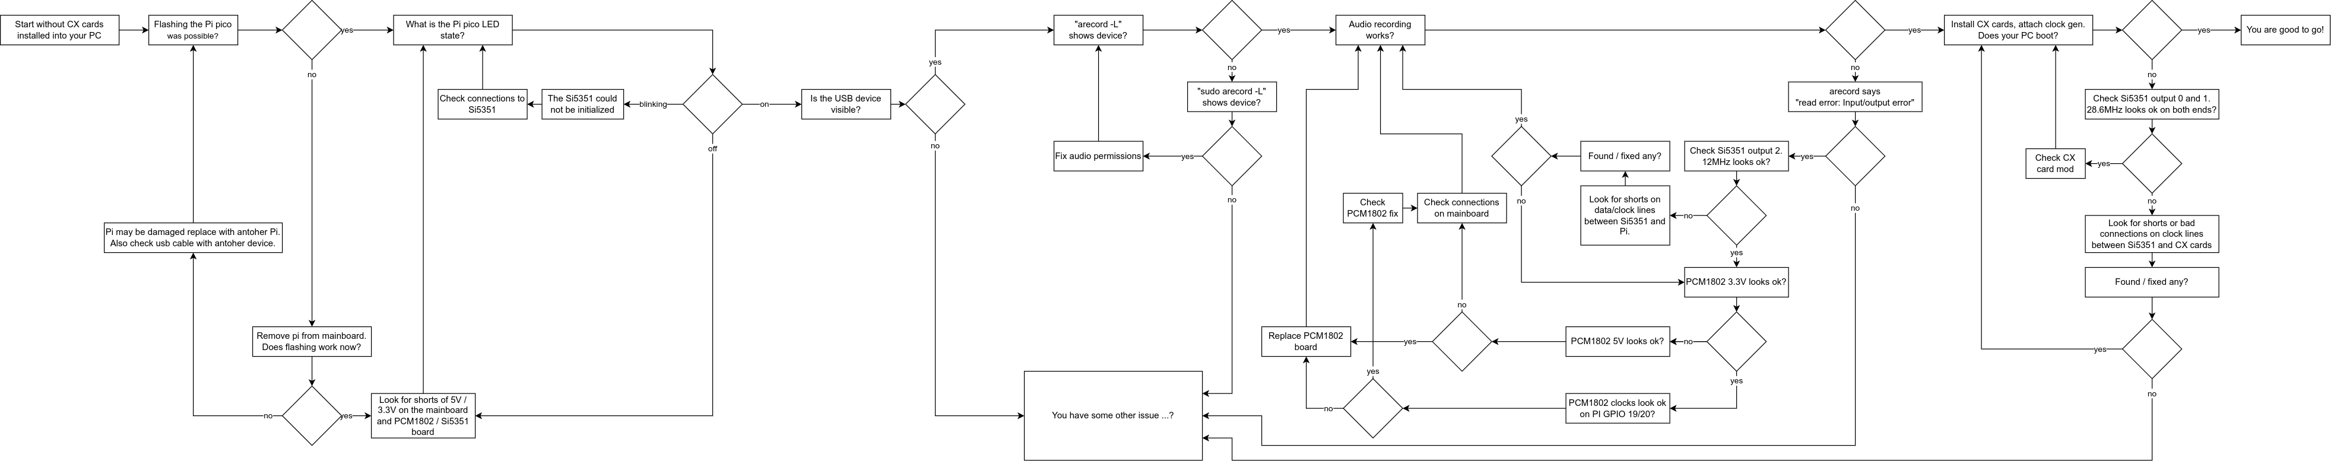
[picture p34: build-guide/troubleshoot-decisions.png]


If the diagram leads you in a loop then you may have a problem that is not covered here.
You can look at the ["Other issues"][self-other-issue] section.

### Flashing the Pi pico

The Pi pico has a boot loader that cannot be overwritten.
Have a look [here](https://www.okdo.com/getting-started/get-started-with-raspberry-pi-pico/) on how to flash it.
You can download the mentioned [blink.uf2](https://datasheets.raspberrypi.com/soft/blink.uf2) example to check whether your Pi device is generally working.
If you flashed the blink test, make sure to re-flash the clock gen firmware.
The guide will generally assume you have the clock gen firmware installed.

### What is the Pi pico LED state?

Since firmware version 1.1.0, after booting the LED can have 3 states:
- off: early boot stage failed or power is not good
- blinking at about 2 Hz: the Si5351 clock generator could not be found
- on: booting finished normally

### Look for shorts of 5V / 3.3V on the mainboard and PCM1802 / Si5351 board

The following needs a multimeter. 
Unplug all subboards from the mainboard, and test individually, then combined:
- confirm no continuity between the 5V and GND on the PCM1802 board and mainboard.
- confirm no continuity between the 5V / VBus on the Pi and GND.
- confirm no continuity between the 3.3V / Vin and GND on the Si5351 board and mainboard.
- confirm continuity on 5V / VBus across all boards.
- confirm continuity on GND across all boards.

Note both the PCM1802 and Si5351 have passive and active component on them.
This will cause a reading of a couple 100k Ohms from any of 3.3V/5V pins to GND on the boards.
This is normal and only if your reading is below about 1000 / 1k Ohms it should be counted as a short.

### Check connections to Si5351

The following needs a multimeter.
- confirm no continuity between the Vin and GND on the Si5351 board.
- confirm no continuity between the 3.3V on the Pi and GND.
- confirm continuity on 3.3V, GND, SDA, SCL from Pi to Si5351 board.

### Is the USB device visible?

This tells you whether the USB enumeration (when a USB host discovers a USB device) was successful.
Run `lsusb` as a normal user, check if the output contains this line:

```
Bus 002 Device 003: ID 1209:0001 Generic pid.codes Test PID
```

If yes, it means the host can talk to the clock gen.
If no, then the USB communication is not working, either due to an electrical problem on the connection, or a non-working firmware on the Pi pico.

### Look for shorts on the mainboard

The following needs a multimeter, and both the PCM1802 and Si5351 board unplugged from the mainboard.
- confirm no continuity between the GND plane and any of the power pins on the Pi pico, PCM1802 and Si5351 connectors.

Remove any shorts / solder bridges you find.

### `arecord -L` / `sudo arecord -L` shows device?

This tells you whether the ALSA sound system correctly detected the clock gen as a sound card.
Run `arecord -L` as a normal user, check if the output contains these lines:

```
hw:CARD=CXADCADCClockGe,DEV=0
    CXADC+ADC-ClockGen, USB Audio
    Direct hardware device without any conversions
```

If they show up, everything is fine, if not retry with `sudo arecord -L`.
If they show up now, it means your normal user misses the permissions to do audio capture.
If they still don't show up, its another problem, that is not covered here.

### Fix audio permissions

This depends on the linux distribution you have.
Under debian / ubuntu based OS, your user needs to be in the `audio` group to be able to capture or play audio.
So add your user to the `audio` group, [see these steps](https://askubuntu.com/questions/79565/how-to-add-existing-user-to-an-existing-group).

### Audio recording works?

Run the following command:

```bash
arecord -D hw:CARD=CXADCADCClockGe -c 3 -r 46875 -f S24_3LE --samples=1000 test.wav
```

It should respond with only the following and produce a file called `test.wav` that is around 9kb in size.

```
Recording WAVE 'test.wav' : Signed 24 bit Little Endian in 3bytes, Rate 46875 Hz, Channels 3
```

If the outputs includes something like the following, then recording did not work as expected.

```
arecord: pcm_read:2221: read error: Input/output error
```

The above generic "read error: Input/output error" error can have multiple reasons.
But it is a good indication that no data is coming from the PCM1802 sub board to the Pi.

Since firmware version 1.1.0 the audio output can be switch to a debug mode.
Open `alsamixer`, select the clock gen sound card (F6), select the capture controls (F4), and mute "Audio Control" by pressing the *space bar*.
When muted the text "CAPTURE" should be replaced with "---------".
Retry the above `arecord` command, if it is successful, then there is a problem with the data from the PCM1802 subboard.
The wav file contains a dump of the content of the global status structure found in [global_status.h][code-status].
This may be able to tell you which lines are affected (LRCK/BCK/DATA).

### Check Si5351 output 0/1/2

The following check needs a [DSO][wiki-dso].
You may be able to use a multimeter if it has a frequency counter that goes high enough.
See ["Installation - firmware"][self-clk-wave] for expected wave form and frequency per output.
If outputs 0 and/or 1 are connected to the adapter board, check the clock signal on both ends (mainboard and adapter board).

### Look for shorts on data/clock lines between Si5351 and Pi.

The following needs a multimeter, both Pi and Si5351 must be plugged onto the mainboard.
Check continuity on the SCL and SDA lines from Si5351 to Pi.
Check no continuity on the SCL and SDA lines to GND or 3.3V.
Beware that the SCL and SDA lines have pull-ups, of a couple kOhms, so only a very low resistance (less than 10 Ohms) should be counted as short.

### PCM1802 3.3V / 5V looks ok?

The following needs a multimeter, both Pi and PCM1802 must be plugged onto the mainboard. 
The PCM1802 board has an onboard regulator that converts the 5V from the USB (VBus on Pi) down to 3.3V.
Both the converted 3.3V and 5V are available on the PCM1802 pin header.
While clock gen is powered up, check those voltages to GND.

### PCM1802 clocks look ok on PI GPIO 19/20?

The following check needs a [DSO][wiki-dso].
You may be able to use a multimeter if it has a frequency counter that goes high enough.
- The LR clock pin ("LRCK") from the PCM1802 is connected to GPIO 20 in the PI.
  Check that this carries a 48kHz or 46kHz clock signal.
  Verify both ends.
- The Bit clock pin ("BCK") from the PCM1802 is connected to GPIO 19 in the PI.
  Check that this carries an about 3MHz clock signal.
  Verify both ends.

If the clocks are absent or heavily distorted, look for shorts / bridges on the PCM1802 pin header.

Since firmware version 1.1.0 the audio output can be switch to a debug mode.
Executing the [info collection script][scripts] will do that (debug.wav).
This will dump the content of the global status structure found in [global_status.h][code-status].
It contains flags that indicate activity on the three PCM1802 lines, which could help to find the problematic connection.

### Check PCM1802 fix

The following needs a multimeter, the PCM1802 board can optionally be removed from the mainboard.
Make sure both bridges `MODE0` and `MODE1` on the underside of PCM1802, are closed and connected to 3.3V.
See above build guide for images and more details.

### Check CX card mod

Under good light conditions, recheck that:
- all the components were removed correctly 
- no solder bridge remains
- the wiring is correct

See above build guide for images and more details.

### You have some other issue ...?

As said initially this guide cannot cover all possible combinations of problems.
But you could:
- retry the debugging / troubleshooting steps to make sure you didn't over look something
- use a different PC and/or USB port
  - do not use a USB hub those can cause issues
  - if you use a USB3 port, try a USB2 port
- use a different [revision of the clock gen firmware][releases]
- use the [info collection script][scripts] and ask for help on the domesday discord server (see instructions [here][discord])

[jlcpcb]: https://jlcpcb.com
[pcbway]: https://www.pcbway.com
[pcm1802-product]: https://www.ti.com/product/PCM1802
[ali-pcm1802-search]: https://www.aliexpress.com/w/wholesale-PCM1802.html?SearchText=PCM1802
[pi-pico]: https://www.raspberrypi.com/products/raspberry-pi-pico/
[si5351-adafruit]: https://www.adafruit.com/product/2045
[cxadc]: https://github.com/happycube/cxadc-linux3/
[kicad]: https://www.kicad.org/
[vhs-decode-wiki-cxcard]: https://github.com/oyvindln/vhs-decode/wiki/CX-Cards
[releases]: https://gitlab.com/wolfre/cxadc-clock-generator-audio-adc/-/releases
[wiki-dso]: https://en.wikipedia.org/wiki/Digital_storage_oscilloscope
[scripts]: ../scripts
[discord]: https://github.com/happycube/ld-decode
[self-clk-wave]: #installation-firmware
[self-other-issue]: #you-have-some-other-issue-
[code-status]: ../firmware/src/global_status.h

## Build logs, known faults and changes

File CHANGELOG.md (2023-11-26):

# Changelog

All notable changes to this project will be documented in this file.

The format is based on [Keep a Changelog](https://keepachangelog.com/en/1.0.0/),
and this project adheres to [Semantic Versioning](https://semver.org/spec/v2.0.0.html).

## [Unreleased]

## [1.1.0] - 2023-11-26

### Changed

- Firmware - USB / UAC2 device now registers as a line-in capture device which is more appropriate than the previous "microphone"

### Added

- Firmware - Supports debug output (via a mute switch on a feature unit, in-place of the normal audio data)
- Doc - Add SMA edge connector options for clock lines
- PCB - VT610ex clock generator adapter - Rev D (SMA edge mount improvements)
- PCB - VT610ex clock generator adapter - Rev C (Silkscreen updates to get PcbWay support)
- PCB - Clock generator main board - Rev C (PcbWay gerbers)
- Doc - Add troubleshooting guide
- Scripts - Add a script to collect some information on a system to help trouble shoot

## [1.0.0] - 2023-10-08

### Added

- Scripts - Add a script to capture all 3 streams in parallel
- Mechanical - Add a PC bracket in 2 and 3 RCA jacks variant to accommodate PCM1802 ADC inputs and head switch signal
- Mechanical - Add an optional mountable holder to the 3D printable box
- Firmware - USB device descriptor now has correct SemVer in bcdDevice version field
- Firmware - Implement PCM1802 data streaming and head switch GPIO sampling
- Doc - Add example scope trace for 28.6 MHz clock to build and install guide

### Fixed

- Doc - Overview diagram was missing head-switch signal and wrongly stated 16Bit instead of 24Bit audio

## [0.2.0] - 2023-10-02

### Added

- Doc - Initial build and install guide
- Firmware - Implement UAC2 device to control Si5351 clock generator, only dummy data returned, PCM1802 is not yet used
- Mechanical - Add a simple 3D printable box to contain the clock generator

### Fixed

- PCB - Clock generator main board - Rev C (3.3V from PCM1802 erroneously driven by Pi Pico, should be open)

## [0.1.0] - 2023-09-24

### Added

- Firmware - Setup fixed 40 Mhz output
- Firmware - Add Si5351 Adafruit library and convert it to Pi Pico SDK C from C++ Arduino
- Firmware - Firmware build with pipeline and packaging

### Fixed

- PCB - Clock generator main board - Rev B (IO VDD for Si5351 should be 3.3V instead of VSys)

## [0.0.1] - 2023-09-16

### Added

- PCB - VT610ex clock generator adapter - Rev B
- PCB - Clock generator main board - Rev A
- Initial documentation

[unreleased]: https://gitlab.com/wolfre/cxadc-clock-generator-audio-adc/-/compare/v1.1.0...main
[1.1.0]: https://gitlab.com/wolfre/cxadc-clock-generator-audio-adc/-/compare/v1.0.0...v1.1.0
[1.0.0]: https://gitlab.com/wolfre/cxadc-clock-generator-audio-adc/-/compare/v0.2.0...v1.0.0
[0.2.0]: https://gitlab.com/wolfre/cxadc-clock-generator-audio-adc/-/compare/v0.1.0...v0.2.0
[0.1.0]: https://gitlab.com/wolfre/cxadc-clock-generator-audio-adc/-/compare/v0.0.1...v0.1.0
[0.0.1]: https://gitlab.com/wolfre/cxadc-clock-generator-audio-adc/-/tree/v0.0.1

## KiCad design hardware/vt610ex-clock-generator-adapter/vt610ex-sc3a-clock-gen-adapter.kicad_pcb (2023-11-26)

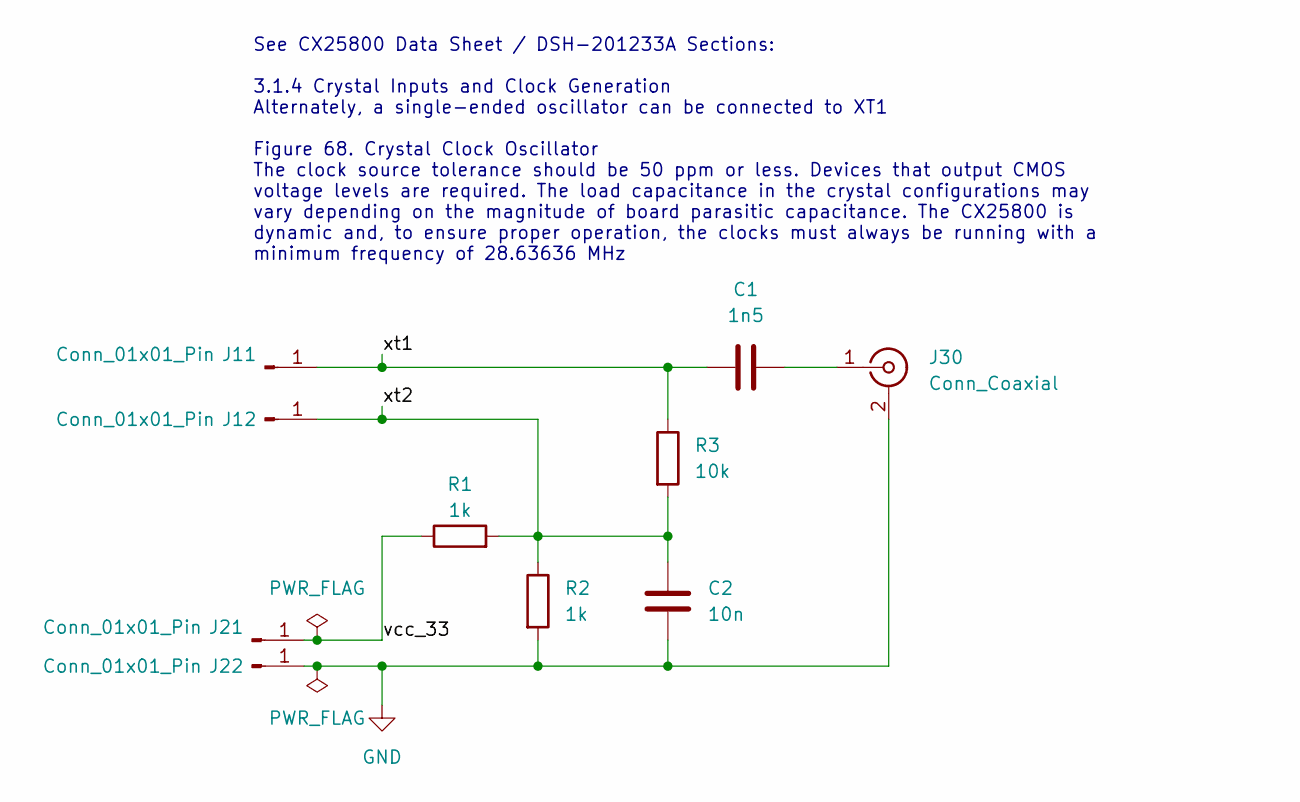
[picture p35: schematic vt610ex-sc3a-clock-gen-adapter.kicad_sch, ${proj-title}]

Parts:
C1: 1n5; C_0805_2012Metric_Pad1.18x1.45mm_HandSolder
C2: 10n; C_0805_2012Metric_Pad1.18x1.45mm_HandSolder
J11, J12, J21, J22: Conn_01x01_Pin; TestPoint_Pad_D2.0mm
J30: Conn_Coaxial; SMA_Samtec_SMA-J-P-X-ST-EM1_EdgeMount
R1, R2: 1k; R_0805_2012Metric_Pad1.20x1.40mm_HandSolder
R3: 10k; R_0805_2012Metric_Pad1.20x1.40mm_HandSolder

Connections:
/vcc_33: J21.1, R1.1
/xt1: C1.2, J11.1, R3.1
/xt2: C2.1, J12.1, R1.2, R2.1, R3.2
GND: C2.2, J22.1, J30.2 (Ext), R2.2
unnamed: C1.1, J30.1 (In)

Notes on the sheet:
See CX25800 Data Sheet / DSH-201233A Sections: 3.1.4 Crystal Inputs and Clock Generation Alternately, a single-ended oscillator can be connected to XT1 Figure 68. Crystal Clock Oscillator The clock source tolerance should be 50 ppm or less. Devices that output CMOS voltage levels are required. The 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

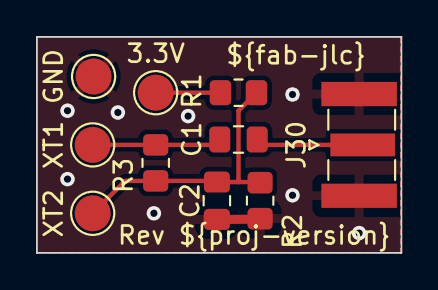
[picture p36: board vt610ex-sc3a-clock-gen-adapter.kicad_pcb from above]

Board: 2 copper layers, 20.2 x 12.0 mm, 10 parts (0 on the bottom side), 5 nets.

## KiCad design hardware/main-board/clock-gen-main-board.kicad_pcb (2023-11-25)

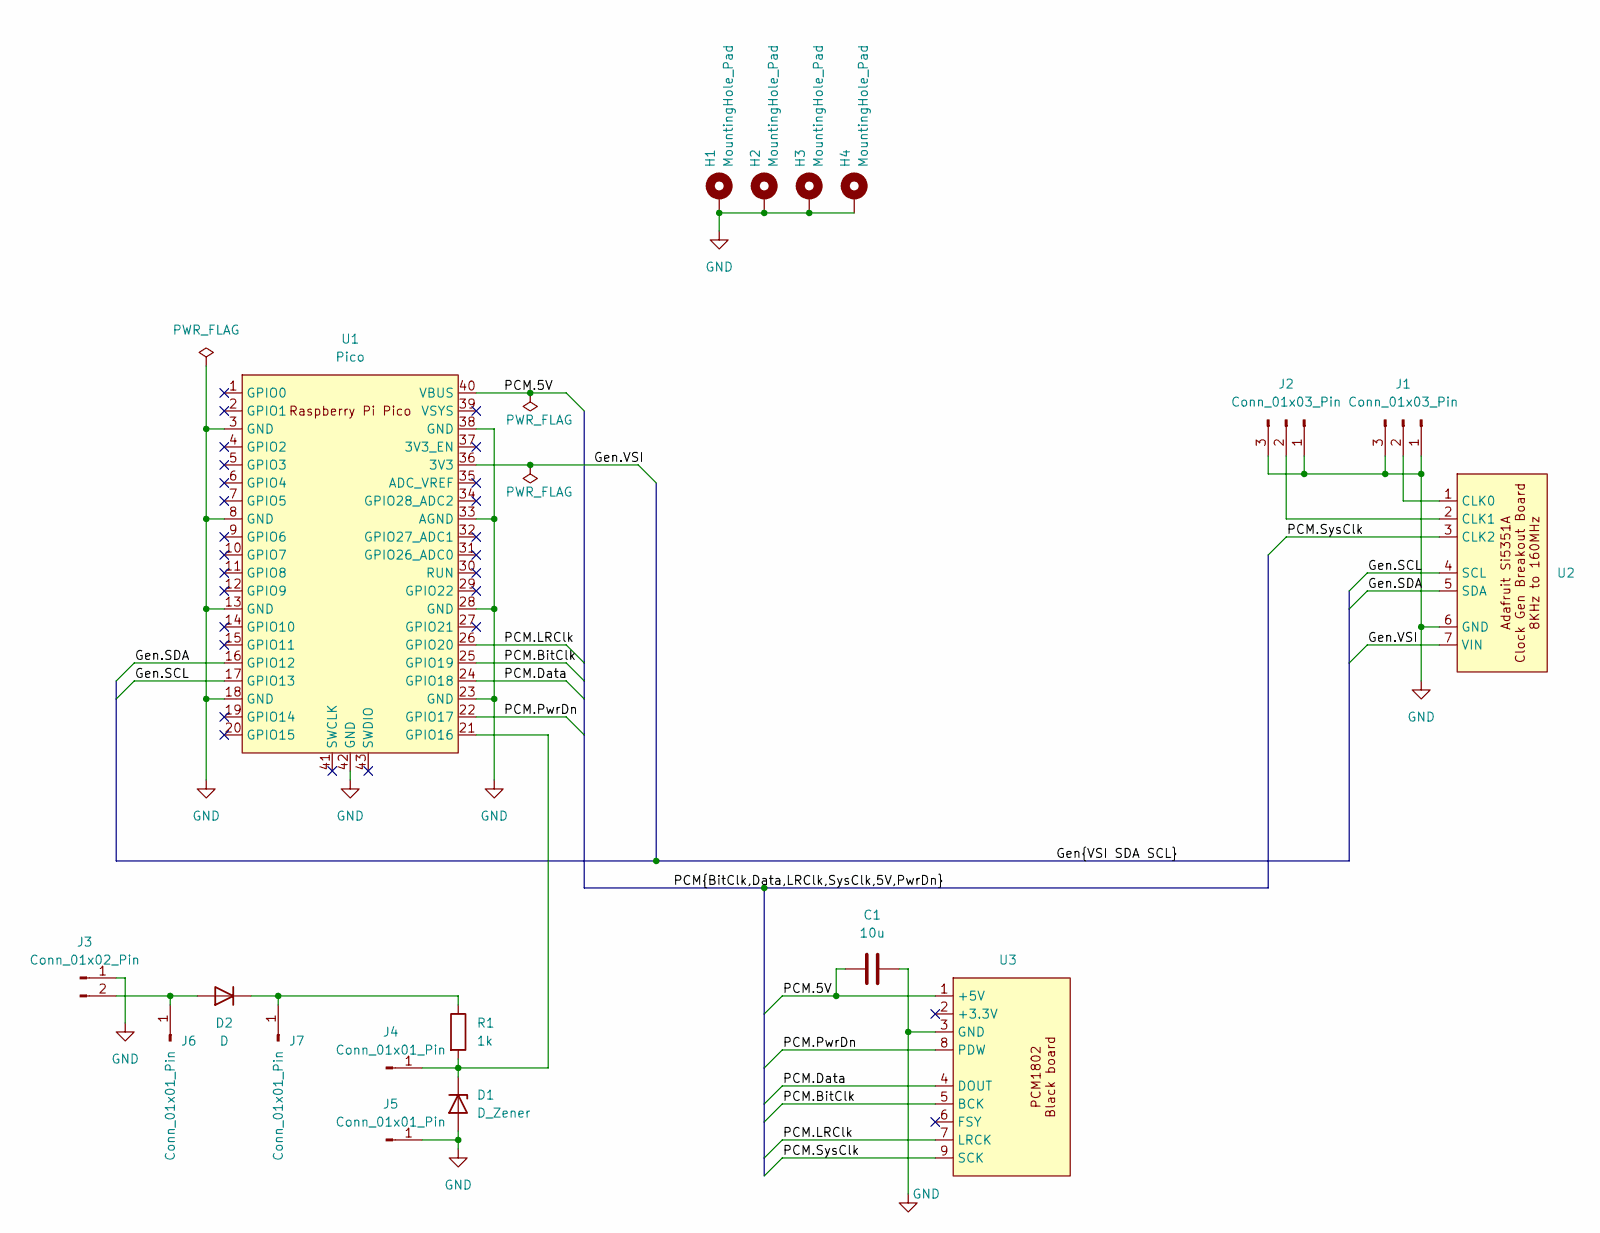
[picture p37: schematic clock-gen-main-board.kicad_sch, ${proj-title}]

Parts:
C1: 10u; C_0805_2012Metric_Pad1.18x1.45mm_HandSolder
D1: D_Zener; D_SOD-123
D2: D; D_SOD-123
H1, H2, H3, H4: MountingHole_Pad; MountingHole_3.2mm_M3_ISO14580_Pad
J1, J2: Conn_01x03_Pin; PinHeader_1x03_P2.54mm_Vertical
J3: Conn_01x02_Pin; PinHeader_1x02_P2.54mm_Vertical
J4, J5, J6, J7: Conn_01x01_Pin; PinHeader_1x01_P2.54mm_Vertical
R1: 1k; R_0805_2012Metric_Pad1.20x1.40mm_HandSolder
U1: Pico; RPi_Pico_SMD_TH
U2: Adafruit_Si5351A_Breakout_Board
U3: black-pcm1802-board

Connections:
/Gen.SCL: U1.17 (GPIO13), U2.4 (SCL)
/Gen.SDA: U1.16 (GPIO12), U2.5 (SDA)
/Gen.VSI: U1.36 (3V3), U2.7 (VIN)
/PCM.5V: C1.1, U1.40 (VBUS), U3.1 (+5V)
/PCM.BitClk: U1.25 (GPIO19), U3.5 (BCK)
/PCM.Data: U1.24 (GPIO18), U3.4 (DOUT)
/PCM.LRClk: U1.26 (GPIO20), U3.7 (LRCK)
/PCM.PwrDn: U1.22 (GPIO17), U3.8 (PDW)
/PCM.SysClk: U2.3 (CLK2), U3.9 (SCK)
GND: C1.2, D1.2 (A), H1.1, H2.1, H3.1, H4.1, J1.1, J1.3, J2.1, J2.3, J3.1, J5.1, U1.3 (GND), U1.8 (GND), U1.13 (GND), U1.18 (GND), U1.23 (GND), U1.28 (GND), U1.33 (AGND), U1.38 (GND), U1.42 (GND), U2.6 (GND), U3.3 (GND)
unnamed: D1.1 (K), J4.1, R1.2, U1.21 (GPIO16)
unnamed: D2.2 (A), J3.2, J6.1
unnamed: D2.1 (K), J7.1, R1.1
unnamed: J1.2, U2.1 (CLK0)
unnamed: J2.2, U2.2 (CLK1)

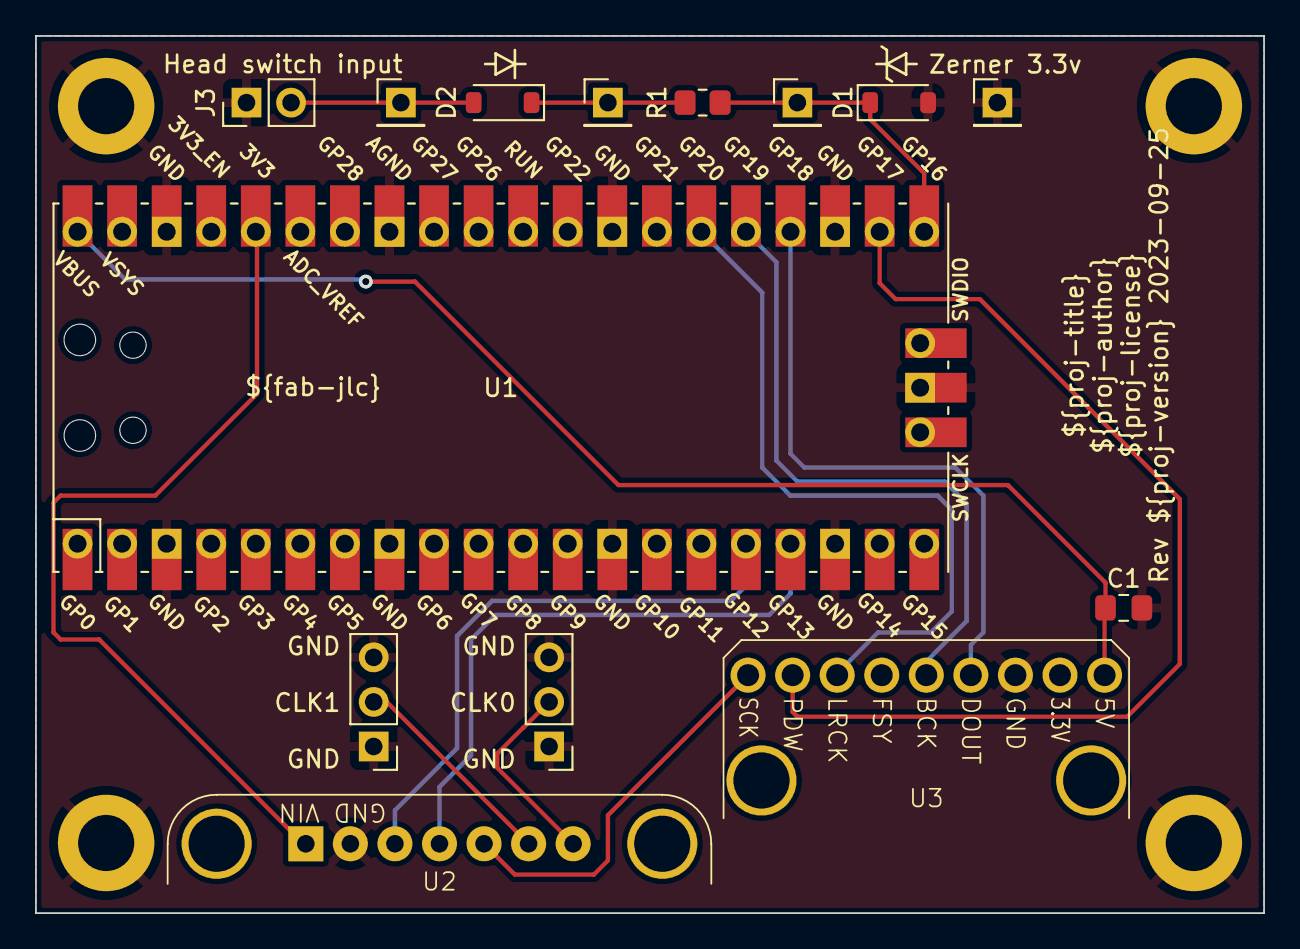
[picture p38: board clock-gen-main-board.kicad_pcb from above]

Board: 2 copper layers, 70.0 x 50.0 mm, 18 parts (0 on the bottom side), 15 nets.

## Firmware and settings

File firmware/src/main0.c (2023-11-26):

// SPDX-License-Identifier: BSD-3-Clause
// Copyright (c) 2023 Rene Wolf

#include <stdlib.h>
#include <stdio.h>
#include <string.h>

#include "pico/stdlib.h"
#include "pico/multicore.h"
#include "pico/unique_id.h"
#include "tusb.h"

#include "build_info.h"
#include "clock_gen.h"
#include "dbg.h"
#include "main1.h"
#include "fifo.h"
#include "usb_descriptors.h"
#include "global_status.h"

int main(void)
{
	const uint led_pin = PICO_DEFAULT_LED_PIN;
	gpio_init(led_pin);
	gpio_set_dir(led_pin, GPIO_OUT);
	
	gpio_put(led_pin, 1);
	dbg_init();
	global_status_init();
	// so the most basic init is done, turn off LED until we are through with the rest
	gpio_put(led_pin, 0);

	bool success = clock_gen_init();
	clock_gen_default(); // all clock gen function do nothing if init was not successful, so we can just call them safely from anywhere
	
	global_status_access(
	{
		global_status.si5351_init_success = global_status_to_boolu8(success);
	});
	
	dbg_say("Running firmware v" NFO_SEMVER_STR "\n");
	dbg_say("Build from " NFO_GIT_SHA "\n");
	
	fifo_init();
	
	dbg_say("multicore launch\n");
	multicore_launch_core1(main1);
	
	char serial[USB_DESCRIPTOR_SERIAL_LEN+1];
	pico_get_unique_board_id_string(serial, sizeof(serial));
	usb_descriptor_set_serial(serial);

	tusb_init();
	dbg_say("tusb_init() done\n");

	while (true)
	{
		// tinyusb device task
		tud_task(); 
		
		// t is now roughly in 250 ms
		uint32_t t = time_us_32() >> 18;
		
		// if clock gen init is not successful then something is really wrong and we blink with about 2Hz, otherwise led is just on
		if( (success) || ((t & 0x1) == 0) )
		{
			gpio_put(led_pin, 1);
		}
		else
		{
			gpio_put(led_pin, 0);
		}
	}

	return 0;
}

//--------------------------------------------------------------------+
// USB Device callbacks
//--------------------------------------------------------------------+

// Invoked when device is mounted
void tud_mount_cb()
{
	// NOOP
	dbg_say("mount\n");
}

// Invoked when device is unmounted
void tud_umount_cb()
{
	// NOOP
	dbg_say("unmount\n");
}

// Invoked when usb bus is suspended
// remote_wakeup_en : if host allow us  to perform remote wakeup
// Within 7ms, device must draw an average of current less than 2.5 mA from bus
void tud_suspend_cb(bool remote_wakeup_en)
{
	// NOOP
	dbg_say("suspend\n");
}

// Invoked when usb bus is resumed
void tud_resume_cb()
{
	// NOOP
	dbg_say("resume\n");
}

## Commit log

2023-09-10 Resolve "Add vt610ex clock gen adapter"
    [vt610ex-sc3a-clock-gen-adapter.kicad_pcb, vt610ex-sc3a-clock-gen-adapter.kicad_sch]
2023-09-11 Resolve "Add main board"
    [adafruit-si5351-breakout.FCStd, clock-gen-main-board.kicad_pcb, clock-gen-main-board.kicad_sch]
2023-09-16 Resolve "Extend mainboard with audio ADC"
    [black-pcm1802-breakout.FCStd, clock-gen-main-board.kicad_pcb, clock-gen-main-board.kicad_sch]
2023-09-16 Resolve "generate fab outputs for pcb production"
    [clock-gen-main-board.kicad_pcb, vt610ex-sc3a-clock-gen-adapter.kicad_pcb]
2023-09-23 fix iovdd
    - create new gerbers
    - create new render
    - update readme
    - update changelog
    [clock-gen-main-board.kicad_pcb, clock-gen-main-board.kicad_sch]
2023-09-25 Resolve "PCM1802 board 3.3V pin is driven instead of open"
    [clock-gen-main-board.kicad_pcb, clock-gen-main-board.kicad_sch]
2023-09-26 Resolve "implement basic stub UAC device"
2023-10-01 Resolve "build 3d printable box enclosure"
    [bottom.stl, enclosure-01.FCStd, lid.stl]
2023-10-02 Resolve "populate pcbs and write build guide"
2023-10-03 Resolve "implement i2s pio and stream pcm1802 adc data"
    [main0.c]
2023-10-06 Resolve "extend enclosure with retainer"
    [box-bottom.stl, box-lid.stl, enclosure-01.FCStd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]
2023-10-06 Resolve "add rca jack pc bracket"
    [bracket-2rca.stl, bracket-3rca.stl, pc-bracket-rca.FCStd]
2023-11-25 Resolve "PCBway Compatible Gerbers"
    [clock-gen-main-board.kicad_pcb, vt610ex-sc3a-clock-gen-adapter.kicad_pcb]
2023-11-26 Resolve "Extend build guide to explain SMA connectors for clock lines"
    [vt610ex-sc3a-clock-gen-adapter.kicad_pcb, vt610ex-sc3a-clock-gen-adapter.kicad_sch]
2023-11-26 Resolve "Extend firmware to offer some debugging options for sub board problems"
    [main0.c]

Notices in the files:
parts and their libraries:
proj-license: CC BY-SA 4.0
